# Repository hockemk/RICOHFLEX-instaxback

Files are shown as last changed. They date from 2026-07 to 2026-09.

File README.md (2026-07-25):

# RICOHFLEX instax back

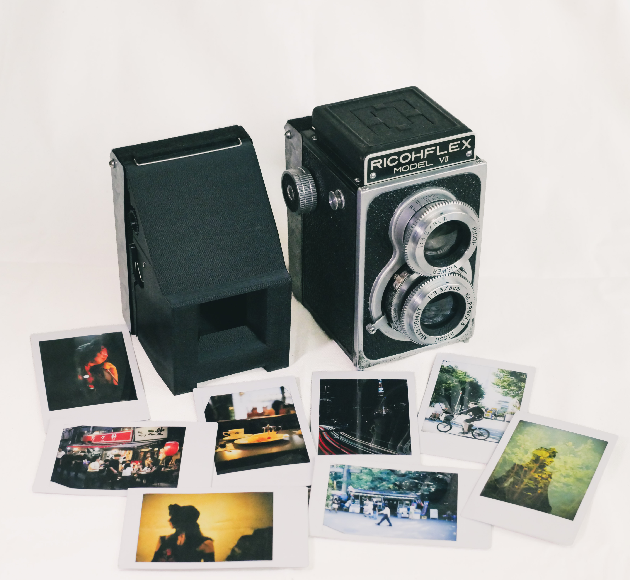
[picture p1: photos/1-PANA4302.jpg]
RICOHFLEX instax back


# RICOHFLEX instax back

RICOHFLEXで**instax mini**フィルムを使用できるようにするための改造キットです。

このリポジトリでは、キットを製作するために必要な3Dデータ、図面、部品表、マニュアルを公開しています。

本プロジェクトは3Dプリント部品を中心に構成されていますが、一部の重要部品には金属加工が必要です。そのため、ある程度の工作設備や加工経験を持つ方向けの内容となっています。

---

## 対応機種

ヘリコイド式のピント調整機構を持つRICOHFLEXに対応しています。

* RICOHFLEX III
* RICOHFLEX VI
* RICOHFLEX VII
など

RICOHFLEX Dia には対応していません。

---

## リポジトリ構成

### `data`

製作に必要なデータをまとめています。

* **bom** - 部品表
* **parts** - STL、STEP、部品図
* **assembly** – 組立に必要なSTEPファイルと組立に関する注意事項
* **extras** - レンズフードなどのおまけデータ

### `manual`

取扱説明書があります。

---

## はじめに

製作を始める前に、以下の手順で進めることをおすすめします。

1. 部品表（BOM）を確認する
2. STL・STEP・図面を確認し、必要な部品を製作する
3. 組立の注意事項とSTEPファイルを参照しながら組み立てる
4. 取扱説明書を確認して使用する

---

## フィードバック

不具合報告、改善案などはウェルカムです。

改良版や派生版を作ったらたら見せてね。

---

## ライセンス

個人での利用、改造、改良は大歓迎です。

本プロジェクトおよび本プロジェクトのデータを利用した製品の商用利用・販売は禁止とします。

詳しくは **LICENSE** をご確認ください。

---

## 開発について

このプロジェクトの開発経緯や設計に関する記事は、ブログで公開しています。同人誌にもまとめました。

開発記録や設計意図に興味のある方は、ぜひそちらもご覧ください。

---

## 連絡先

製作中に困ったことや不具合、対応機種の情報、改善案などがありましたら、お気軽にご連絡ください。

すべてのお問い合わせに対応できるとは限りませんが、お答えできる範囲でできるだけお手伝いします。

また、完成したカメラや撮影した写真、改良版や派生作品なども、ぜひ見せていただけると嬉しいです。

- Blog: https://hocke.hatenablog.com/archive/category/RICOHFLEX%20instax%20back
- X (Twitter): https://x.com/hocke_mk
- Instagram: https://www.instagram.com/hocke__/

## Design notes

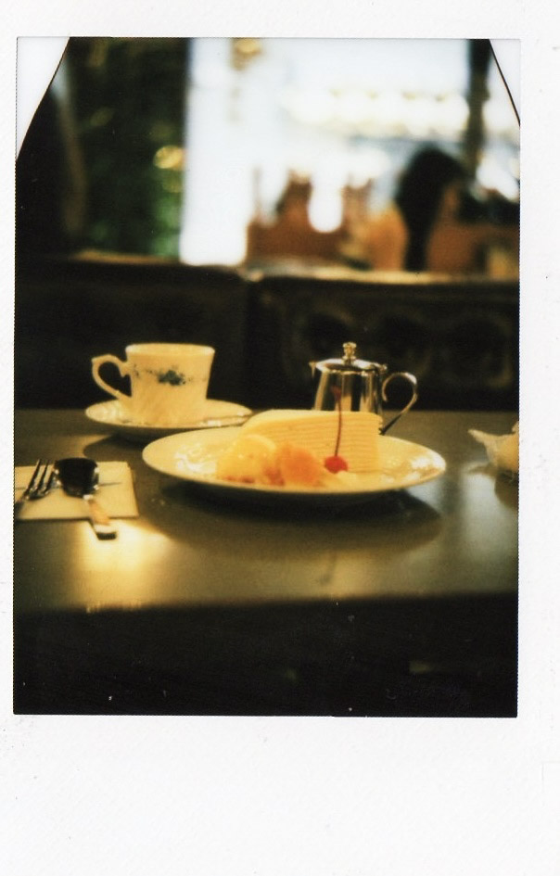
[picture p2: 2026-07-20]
photos/4-IMG_5428.jpg

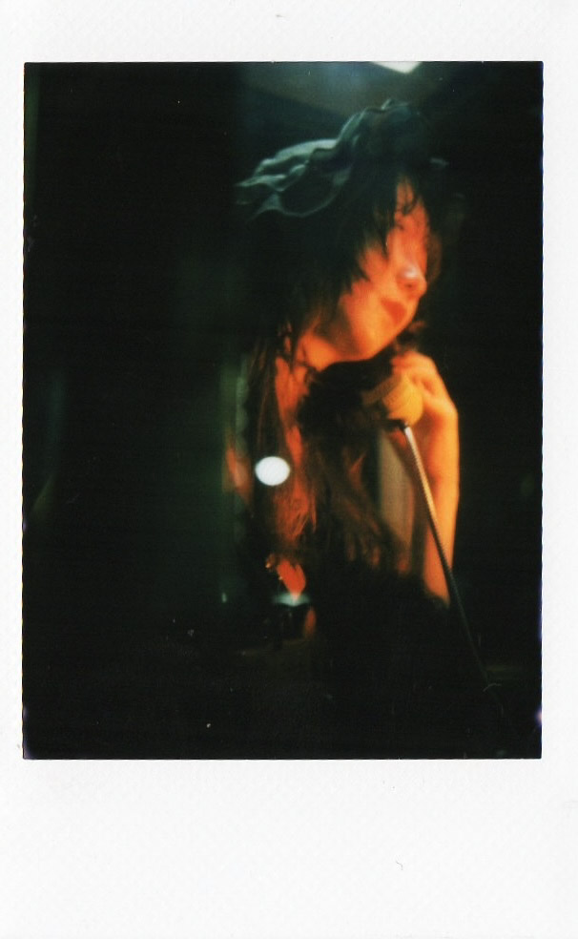
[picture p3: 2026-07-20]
photos/10-IMG_5407.jpg

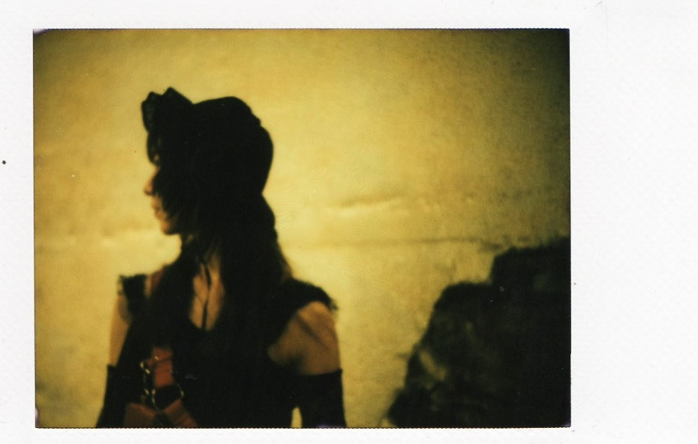
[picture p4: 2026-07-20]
photos/8-IMG_5409.jpg

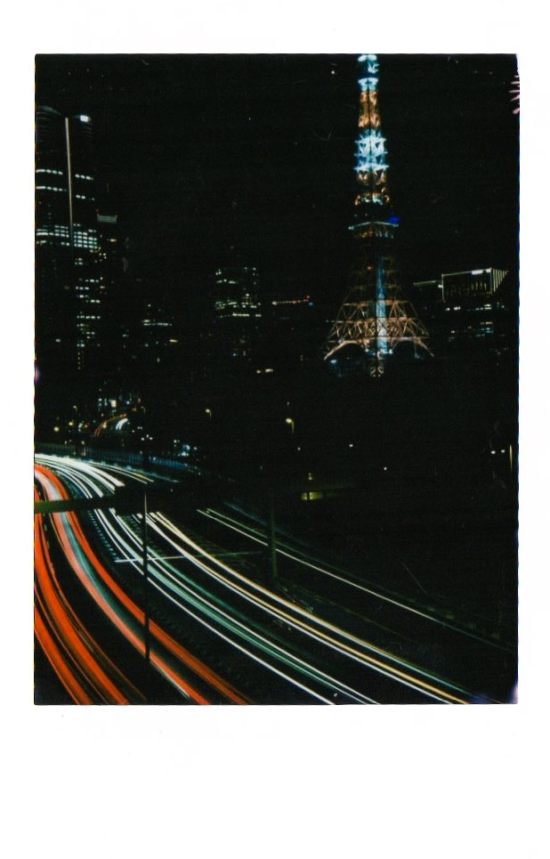
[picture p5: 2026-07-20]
photos/1-IMG_5432.jpg

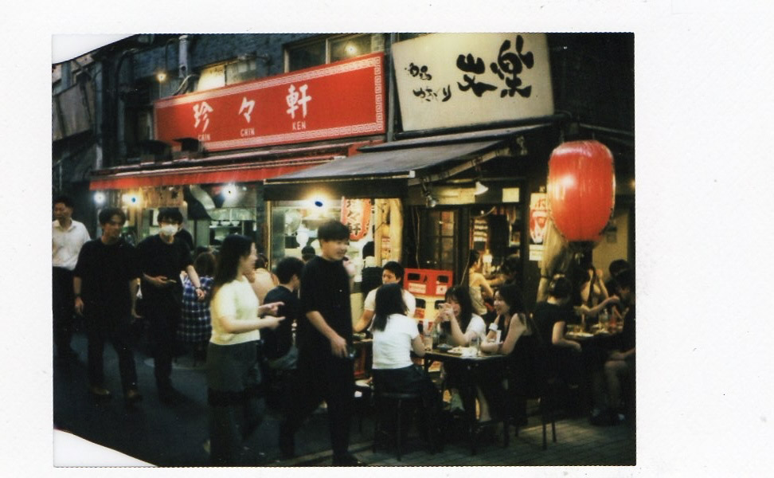
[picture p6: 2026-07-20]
photos/2-IMG_5430.jpg

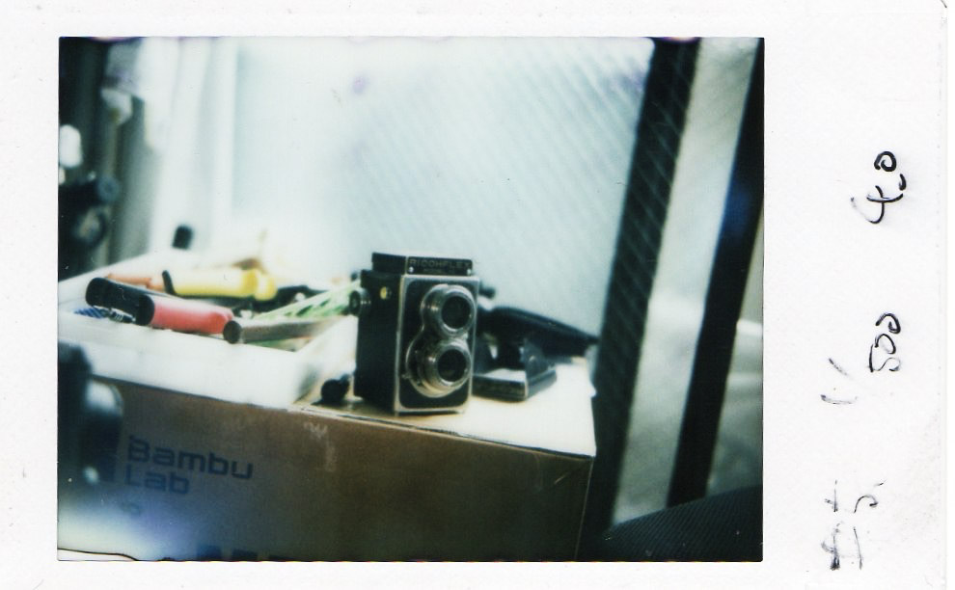
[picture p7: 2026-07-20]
photos/7-IMG_5414.jpg

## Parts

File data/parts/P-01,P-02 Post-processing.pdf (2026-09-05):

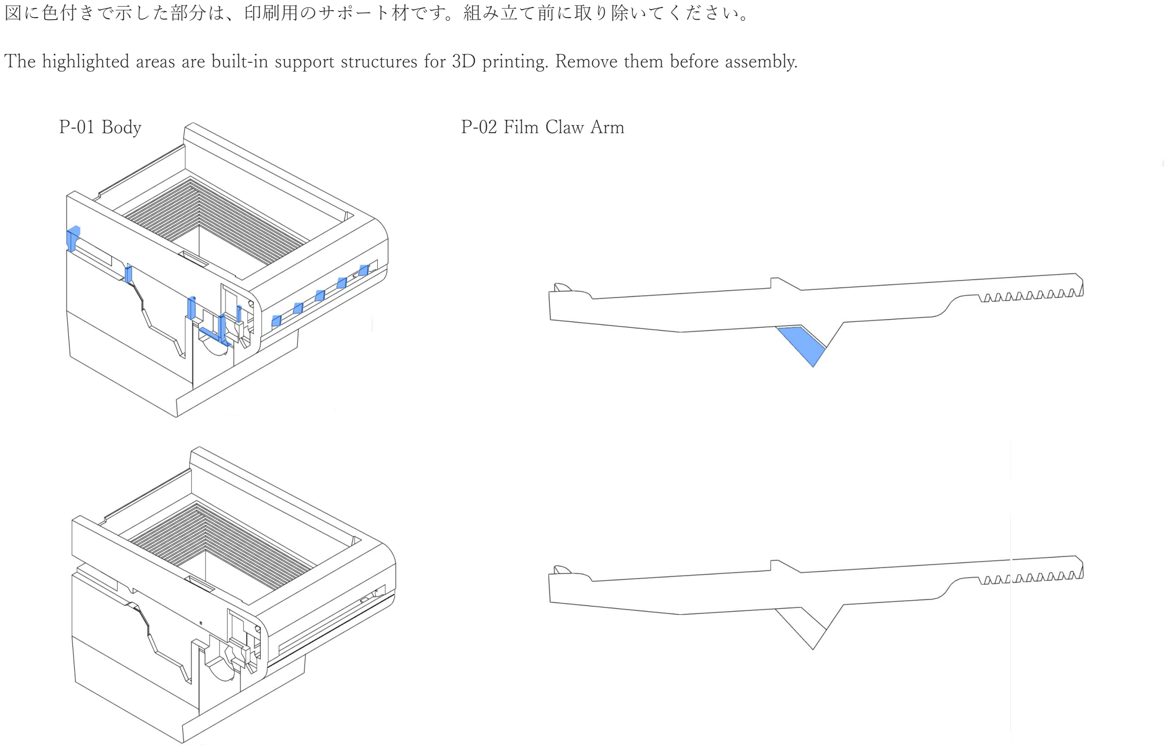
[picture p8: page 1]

図に色付きで示した部分は、印刷用のサポート材です。組み立て前に取り除いてください。

The highlighted areas are built-in support structures for 3D printing. Remove them before assembly.

P-01 Body | P-02 Film Claw Arm

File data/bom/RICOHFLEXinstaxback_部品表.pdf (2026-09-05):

BOM
Part No. | Part name | Qty. | Material/Stock | Specification | Files | Notes
P-01 | Body | 1 | Printed | 0.4mm nozzle | STEP/STL/PDF | Remove the built-in support structures and clean up as needed.
C-01 | Light Seal Felt Strip | 1 | Felt | 5 mm wide × 254 mm | | Adhesive-backed felt recommended. Approx.1mm thick.
C-02 | Light Seal Felt Sheet | 1 | Felt | | SVG/PDF | Cut to match template. Adhesive-backed felt recommended. Approx.1mm thick.
M-01 | Retaining Clip | 1 | Steel Round Bar | Ø1 | PDF | Bend as shown
M-02 | Film Claw | 1 | Stainless Steel Spring Wire | Ø0.4 | PDF | Bend as shown
P-02 | Film Claw Arm | 1 | Printed | 0.2mm nozzle | STEP/STL/PDF | Remove the built-in support structures and clean up as needed.
M-03 | Film Claw Arm Spring | 1 | Stainless Steel Spring Wire | Ø0.4 | SVG | Bend as shown
P-03 | Lever | 1 | Printed | 0.4mm nozzle | STEP/STL
M-04 | Lever Pivot Pin | 1 | Steel Round Bar | Ø0.8 × 4 mm | | Cut to length
P-04 | Knob Gear | 1 | Printed | 0.2mm nozzle | STEP/STL
P-05 | Idler Gear | 1 | Printed | 0.2mm nozzle | STEP/STL
P-06 | Front Roller Gear | 1 | Printed | 0.2mm nozzle | STEP/STL
P-07 | Rear Roller Gear | 1 | Printed | 0.2mm nozzle | STEP/STL
M-05 | Roller Gear Pin | 2 | Steel Round Bar | Ø0.8 × 4.4 mm | | Cut to length
M-06 | Roller Shaft | 2 | Steel Round Bar | Ø3 | PDF | Cut to length and drill holes
M-07 | Roller | 2 | Aluminium Pipe | OD 7 mm × ID 3 mm | PDF | Cut to length and drill a hole
M-08 | Roller Shaft Pin | 2 | Steel Round Bar | Ø0.8 × 5 ｍｍ | | Cut to length
P-08 | Left Roller Retainer | 1 | Printed | 0.4mm nozzle | STEP/STL
P-09 | Right Roller Retainer | 1 | Printed | 0.4mm nozzle | STEP/STL
P-10 | Shaft Spacer | 1 | Printed | 0.4mm nozzle | STEP/STL
M-09 | Roller Pressure Spring | 2 | Stainless Steel Spring Wire | Ø0.8 | SVG | A binder clip spring is a good substitute.
P-11 | Roller Pressure Spring Seat | 1 | Printed | 0.4mm nozzle | STEP/STL
P-12 | Roller Shaft Collar | 2 | Printed | 0.4mm nozzle | STEP/STL
M-10 | Bearing Plate | 2 | Brass Plate | t0.5 | PDF | This part can be made with a drill and files, but a milling machine makes the job much easier.
M-11 | Back Panel | 1 | Metal Sheet | t0.3 | STEP/DXF | Cut and bend as shown. Any sheet metal from approximately 0.2 mm to 0.8 mm thick should work.
C-03 | Film Pack Spring | 2 | Steel | Ø9 × 15 mm Ø0.5 | | Maximum recommended size: Ø9 mm×16 mm, wire Ø0.6 mm. A free length of 14-16 mm works well.
M-12 | Latch Stud | 1 | Steel Round Bar | Ø2 × 2 mm | | Cut to length and weld
C-04 | Foam Tape | 1 | Foam Tape | 3 mm thick
C-05 | Slotted Screw | 2 | Metal | M3 × 12 mm | | Any M3 screw will work. Slotted screws are used only for appearance.
C-06 | Back Panel Leather | 1 | Leather | | SVG/PDF | Cut to match template

3Dプリント部品は、±0.1 mm 以内の寸法精度で印刷してください。推奨積層ピッチは、0.4mmノズルでは0.16mm、0.2mmノズルでは0.1mmです。 フィラメントは、十分な寸法精度と強度が得られるものであればなんでもいいです。私は PLA+ を使用しましたが、PLA-CF、ABS、ナイロンなど、同等以上の性能を持つ材料であれば問題なく使用できるはずです。 この設計は厳密な仕様書ではありません。ご自身の設備や加工方法に合わせて、製作しやすい材料や工法を自由に選択してください。入手しやすく、また扱いやすい材料を使用しちゃってください。 摺動部品については、耐摩耗性を考慮した材料を選択することをおすすめします。 この設計を忠実に再現することよりも、確実に動作することを優先してください。動作性や製作性が向上するのであれば、寸法や材料を変更して問題ありません。 改造改良大歓迎。作ったり改造したらぜひ見せてね。

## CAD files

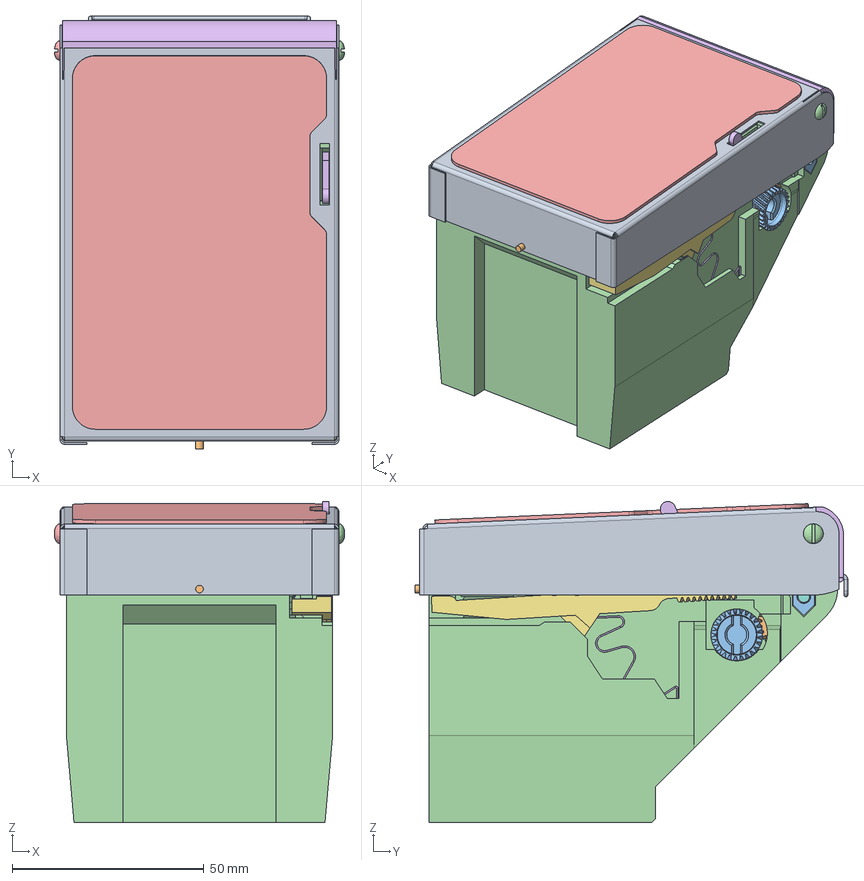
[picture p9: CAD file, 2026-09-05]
data/assemble/Complete_Assembly.step
75.8 x 113.0 x 83.8 mm

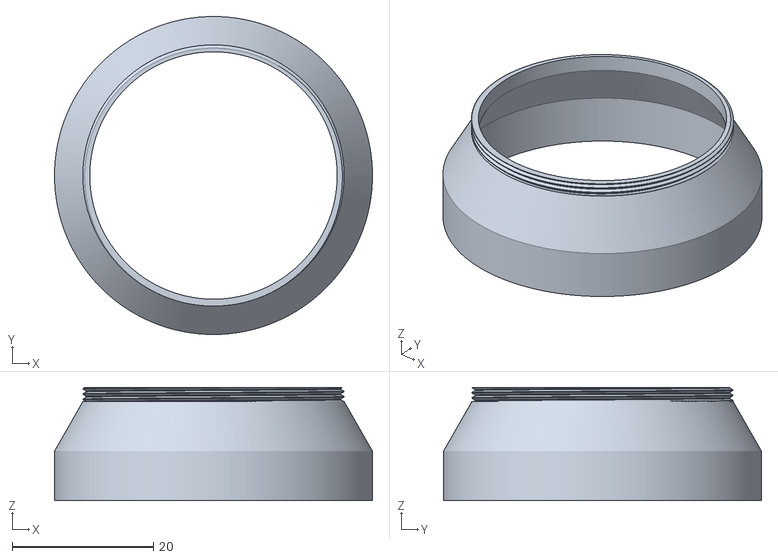
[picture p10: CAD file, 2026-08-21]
data/extras/LensHood37mm.stl
45.0 x 45.0 x 16.0

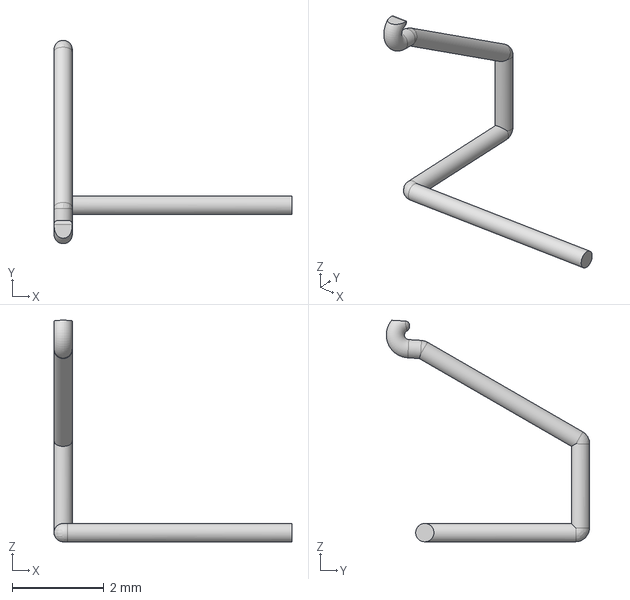
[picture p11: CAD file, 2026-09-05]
data/parts/M-02_FilmClaw.step
5.20 x 4.44 x 4.84 mm

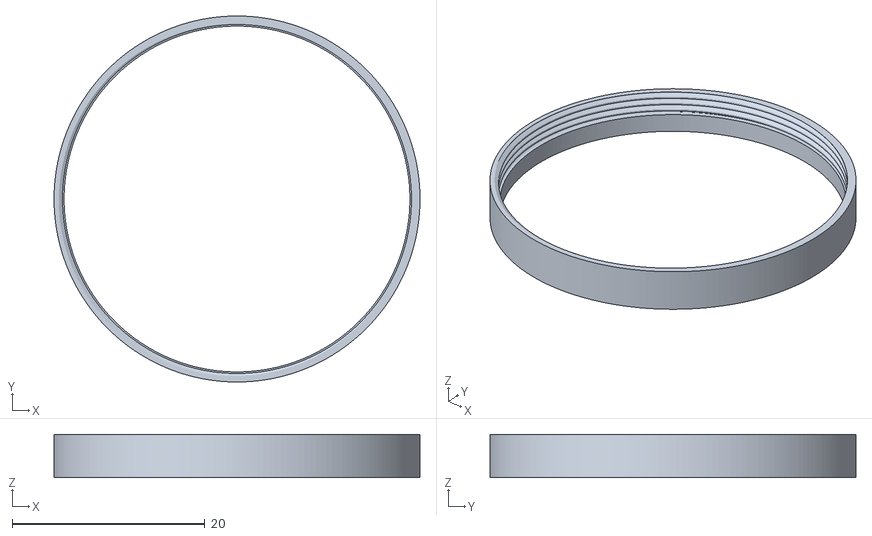
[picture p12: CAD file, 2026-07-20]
data/extras/FilterAdapter37mm.stl
38.0 x 38.0 x 4.50

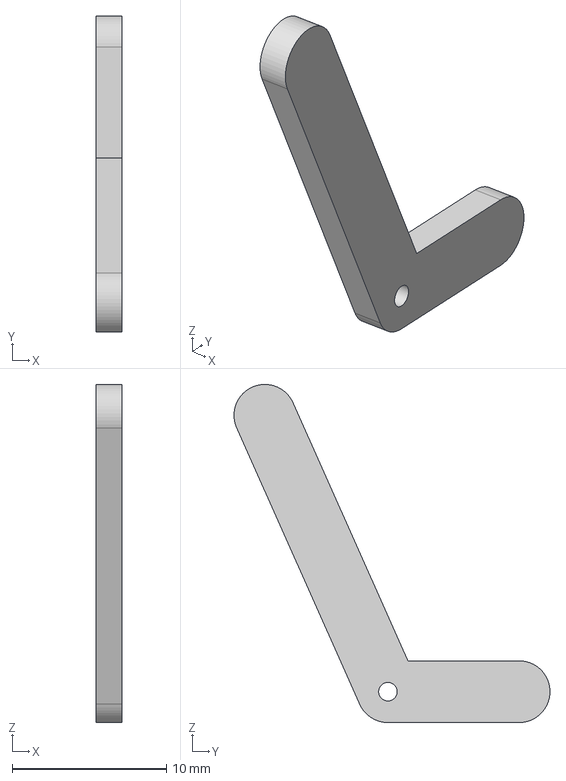
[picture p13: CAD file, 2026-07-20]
data/parts/P-03_Lever.step
1.70 x 20.5 x 21.9 mm

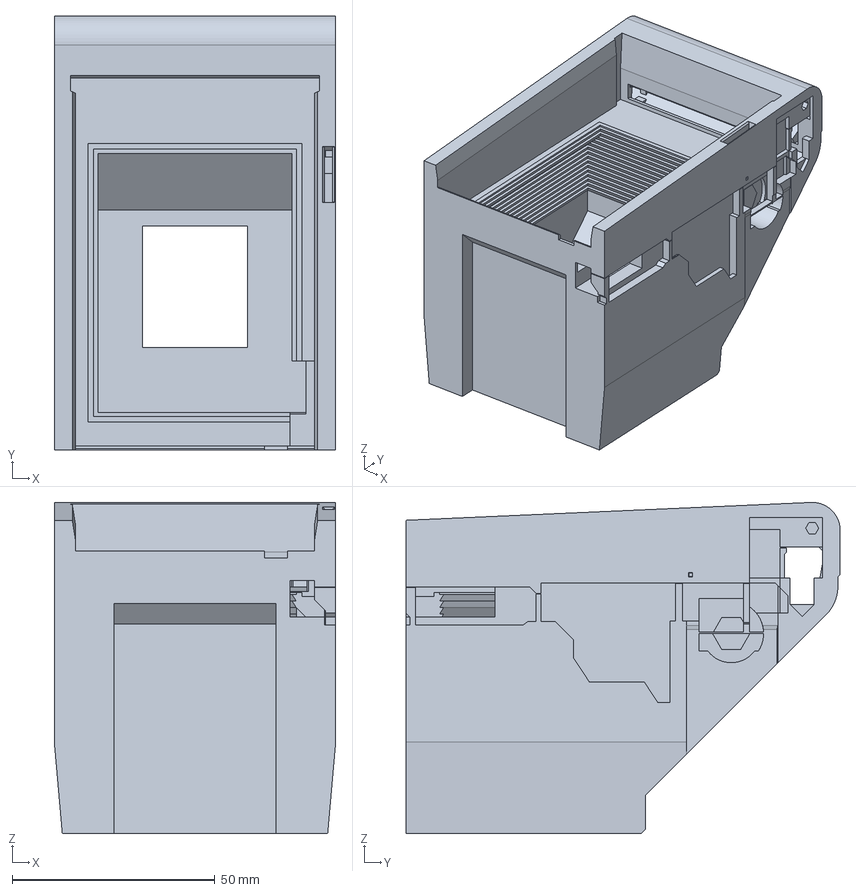
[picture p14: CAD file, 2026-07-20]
data/parts/P-01_body.step
69.5 x 107.2 x 81.8 mm

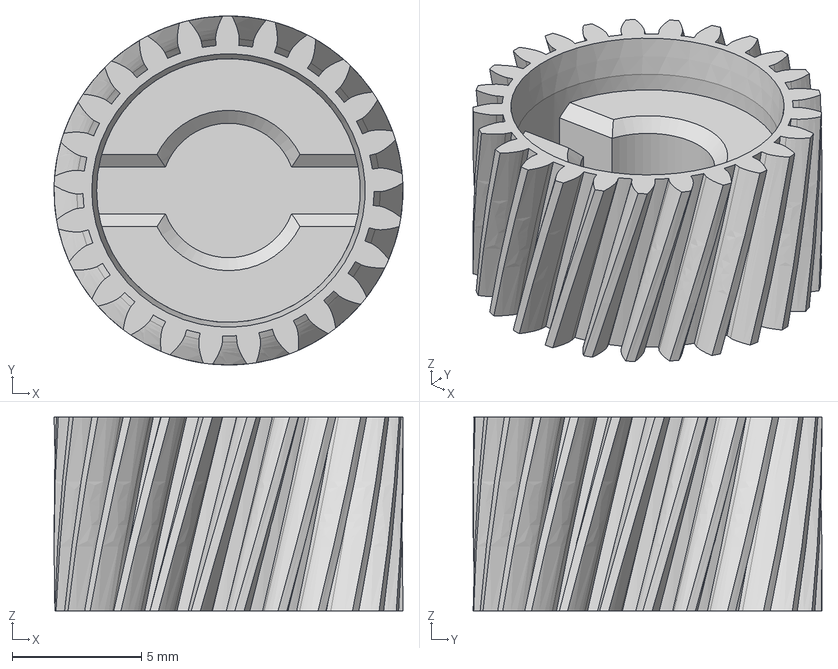
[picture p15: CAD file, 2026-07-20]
data/parts/P-04_KnobGear.step
13.5 x 13.5 x 7.50 mm

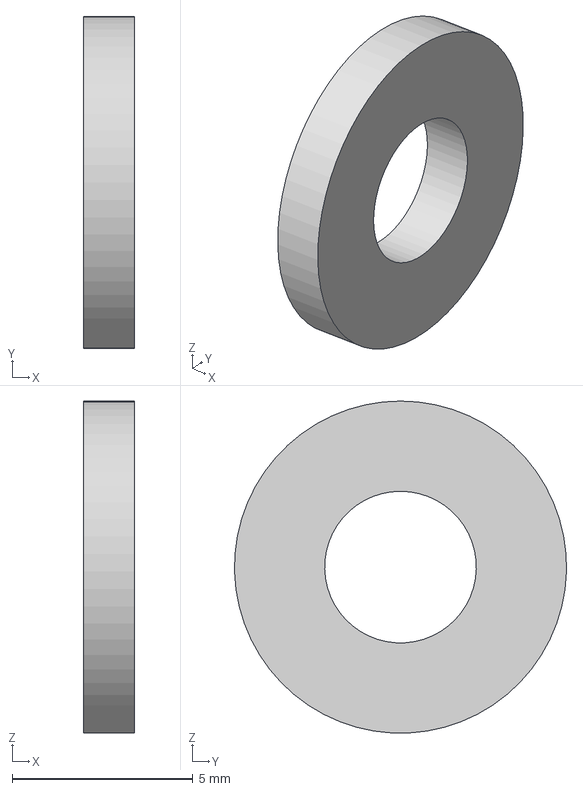
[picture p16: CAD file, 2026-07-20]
data/parts/P-10_ShaftSpacer.step
1.40 x 9.20 x 9.19 mm

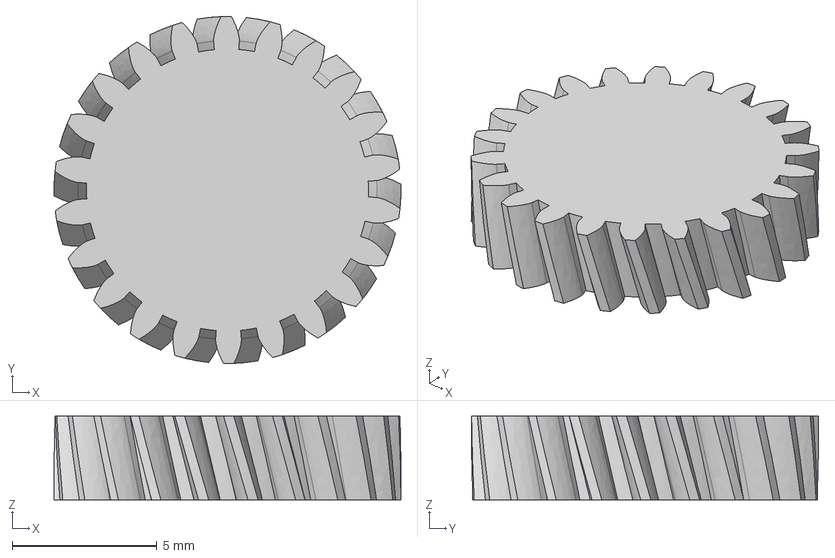
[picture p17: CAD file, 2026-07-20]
data/parts/P-05_IdlerGear.step
12.0 x 12.0 x 2.90 mm

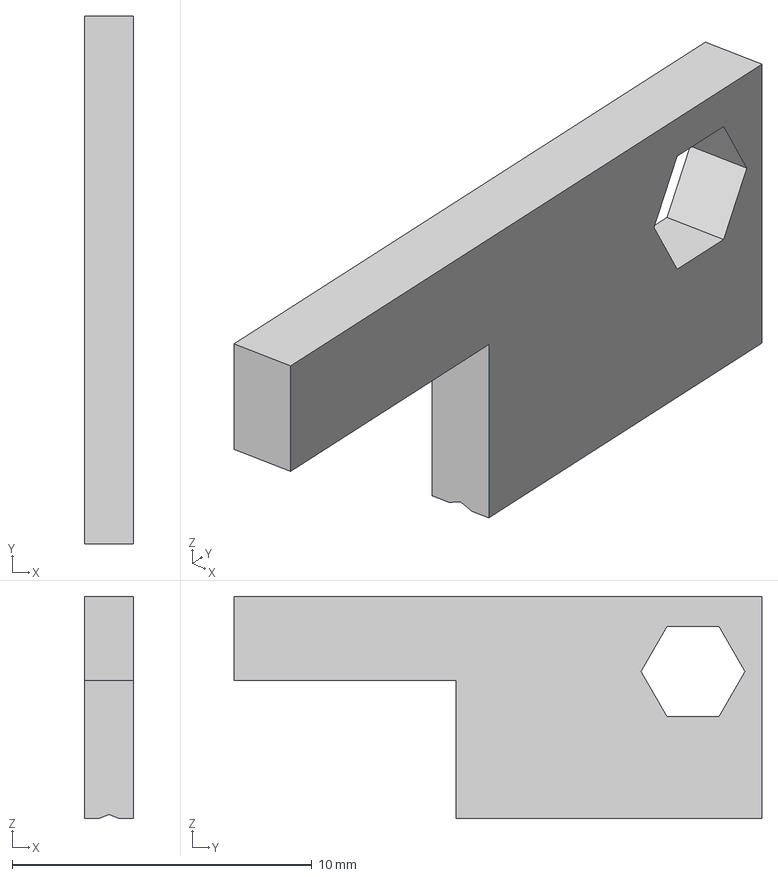
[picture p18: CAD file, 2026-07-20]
data/parts/P-11_RollerPressureSpringSeat.step
1.65 x 17.6 x 7.40 mm

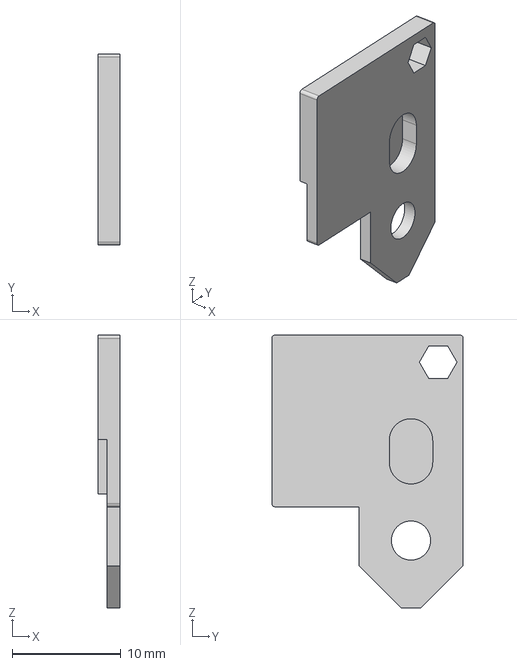
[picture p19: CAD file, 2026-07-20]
data/parts/P-08_LeftRollerRetainer.step
2.00 x 17.6 x 25.1 mm

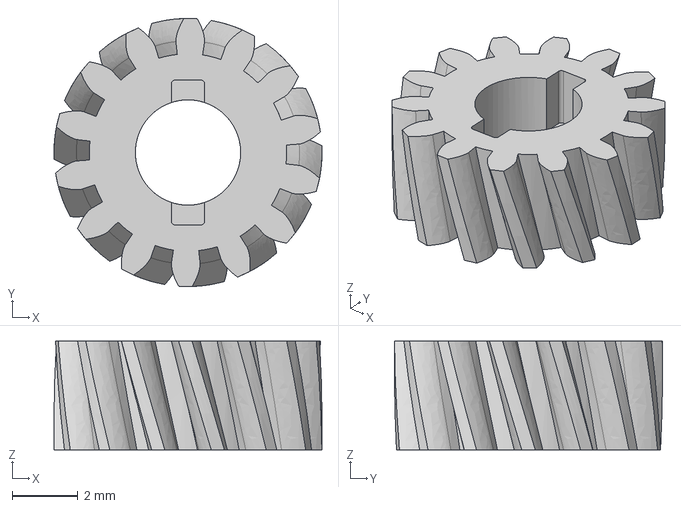
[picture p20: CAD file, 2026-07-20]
data/parts/P-07_RearRollerGear.step
8.14 x 8.15 x 3.30 mm

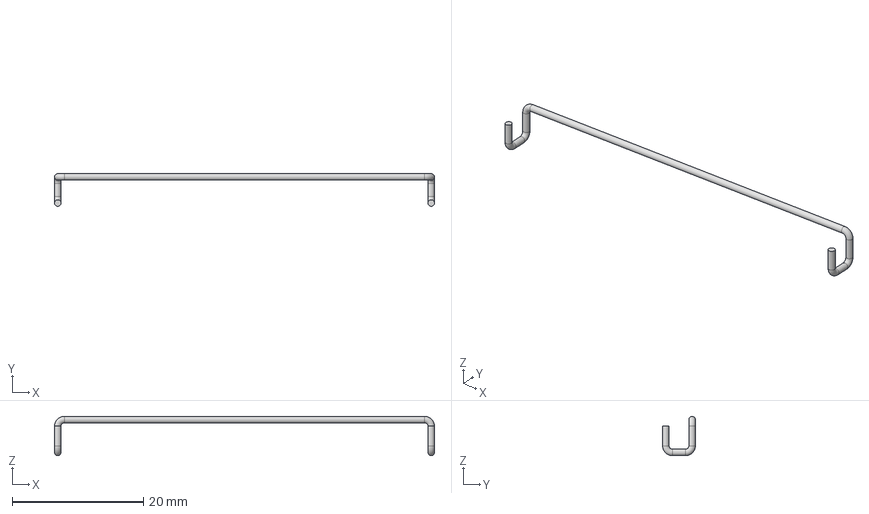
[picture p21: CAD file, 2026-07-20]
data/parts/M-01_RetainingClip.step
58.0 x 5.00 x 6.00 mm

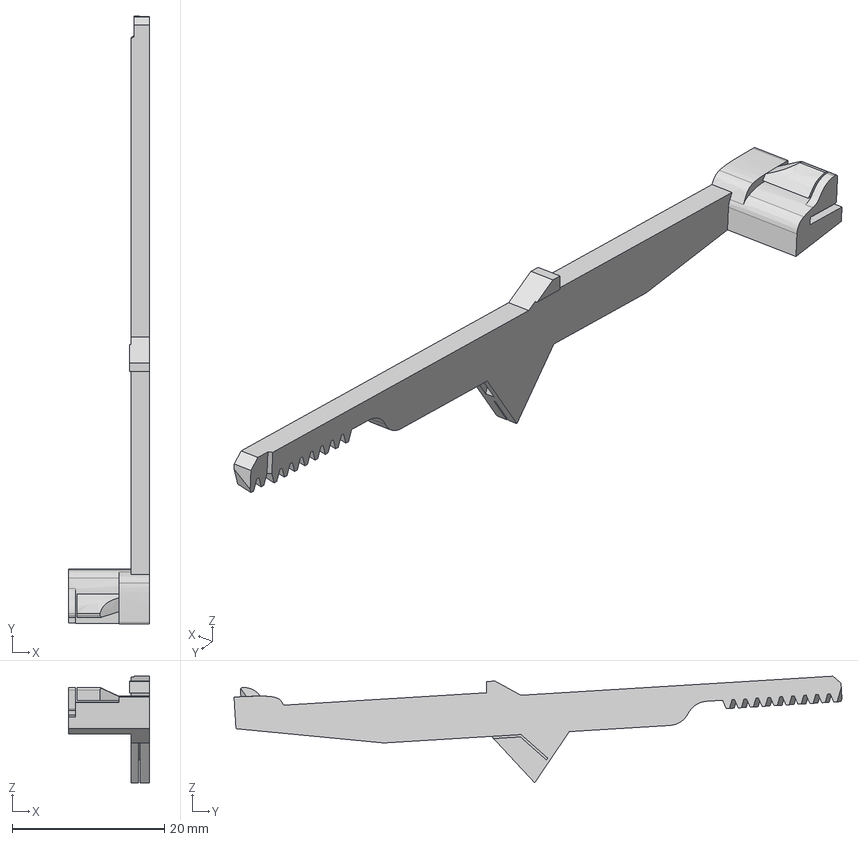
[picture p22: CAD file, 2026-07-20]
data/parts/P-02_FilmClawArm.step
10.6 x 79.7 x 14.0 mm

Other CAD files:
data/parts/P-09_RightRollerRetainer.step
data/parts/P-12_RollerShaftCollar.step
data/parts/P-06_FrontRollerGear.step
data/parts/M-11_BackPanel.step
data/parts/M-11_BackPanel.dxf
data/parts/P-01_body.stl
data/parts/P-02_FilmClawArm.stl
data/parts/P-03_Lever.stl
data/parts/P-04_KnobGear.stl
data/parts/P-05_IdlerGear.stl
data/parts/P-06_FrontRollerGear.stl
data/parts/P-07_RearRollerGear.stl
data/parts/P-08_LeftRollerRetainer.stl
data/parts/P-09_RightRollerRetainer.stl
data/parts/P-10_ShaftSpacer.stl
data/parts/P-11_RollerPressureSpringSeat.stl
data/parts/P-12_RollerShaftCollar.stl

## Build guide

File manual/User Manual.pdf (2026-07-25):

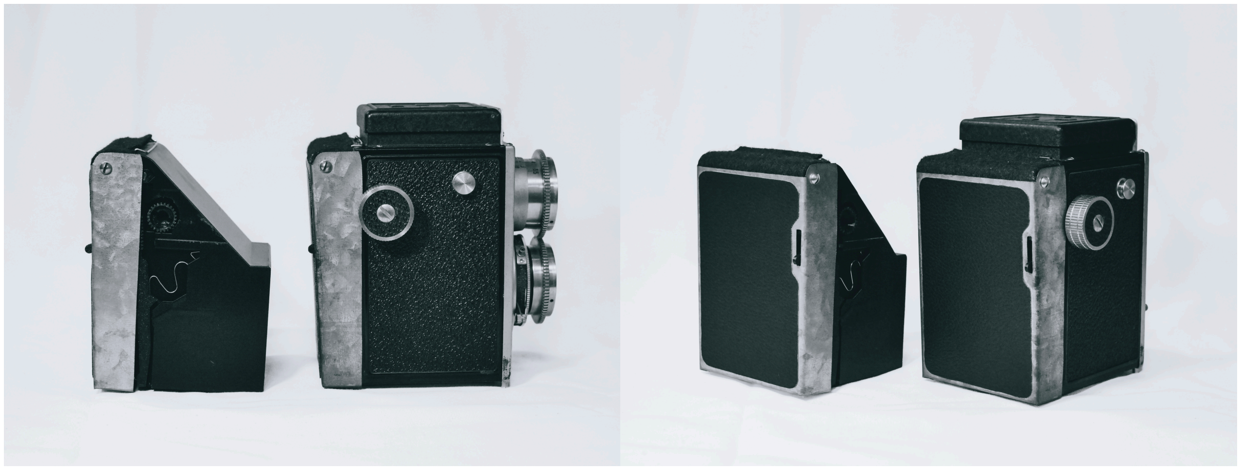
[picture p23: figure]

## Install the Kit

# 〜How to use〜

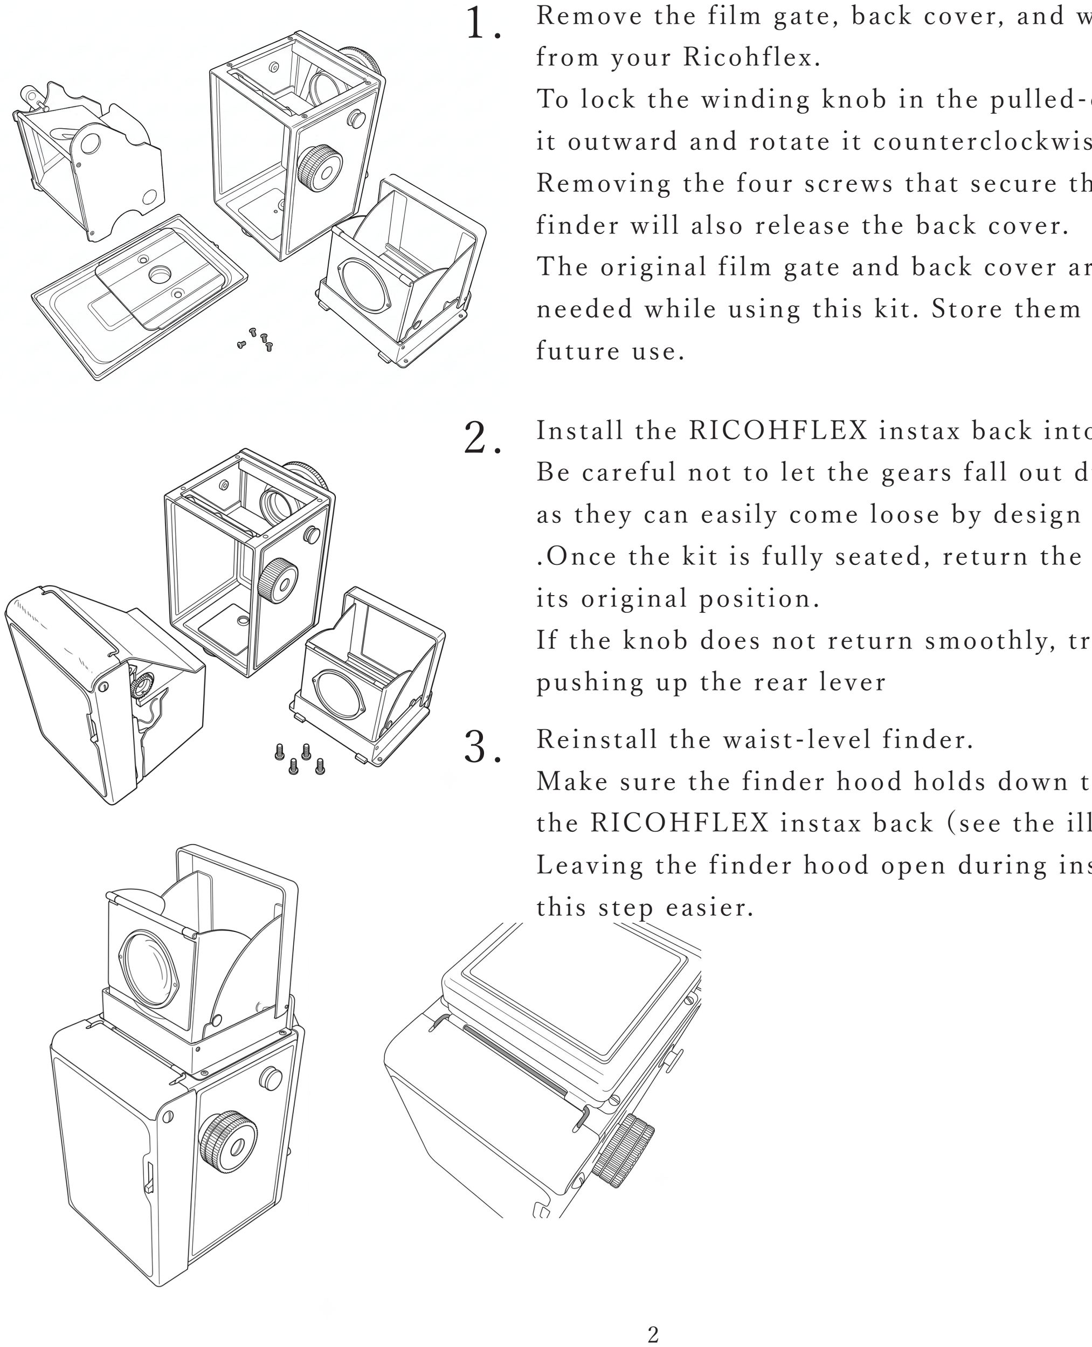
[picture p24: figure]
from your Ricohflex.; future use.; as they can easily come loose by design; its original position.; pushing up the rear lever; Reinstall the waist-level finder.; this step easier.

Remove the film gate, back cover, and waist-level finder

To lock the winding knob in the pulled-out position, pull it outward and rotate it counterclockwise.
Removing the four screws that secure the waist-level finder will also release the back cover.
The original film gate and back cover are no longer needed while using this kit. Store them in a safe place for

Install the RICOHFLEX instax back into the camera.
Be careful not to let the gears fall out during installation,

.Once the kit is fully seated, return the winding knob to

If the knob does not return smoothly, try rotating it while

Make sure the finder hood holds down the upper clip of the RICOHFLEX instax back (see the illustration below). Leaving the finder hood open during installation makes

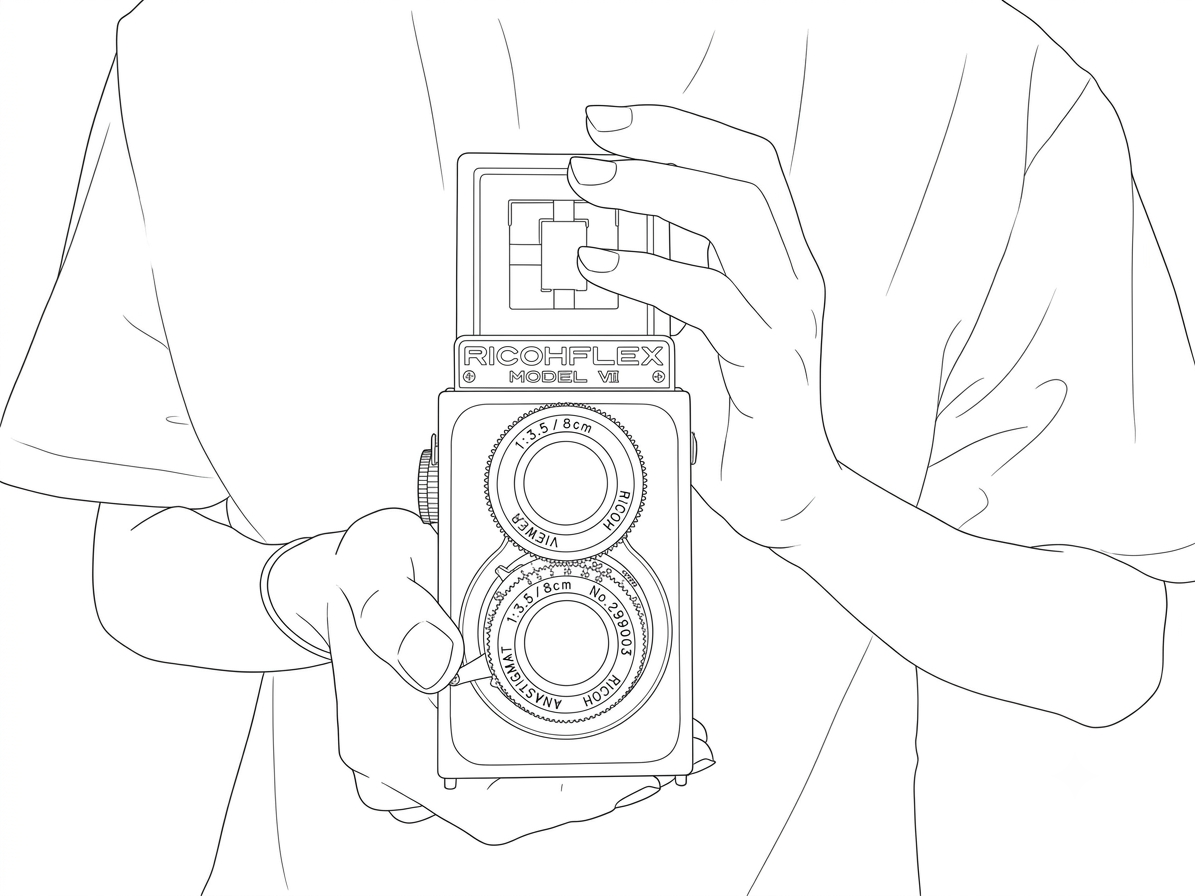
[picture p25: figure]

3

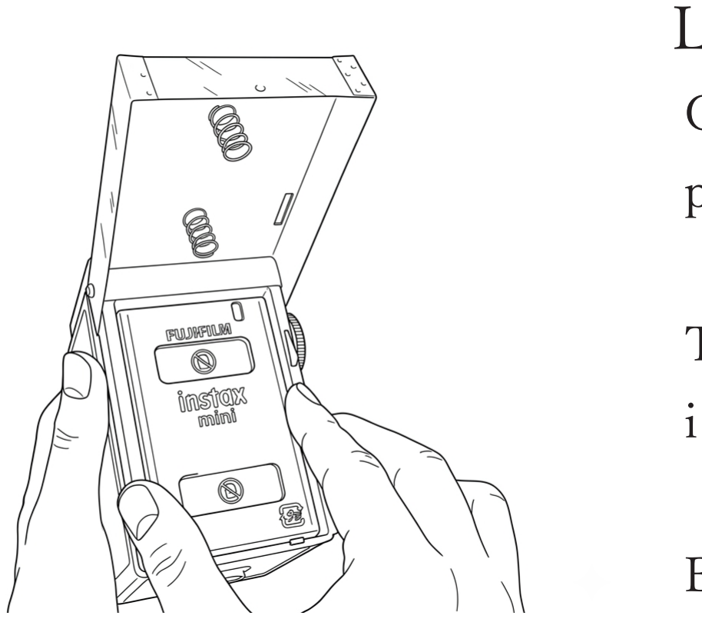
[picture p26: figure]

## Load the Film

Open the back cover and insert an instax mini film pack.

The film is correctly oriented when the yellow mark is visible in the upper-right corner.

Be careful not to catch the film pack on the spring.
SHOOT.

## Eject the Film

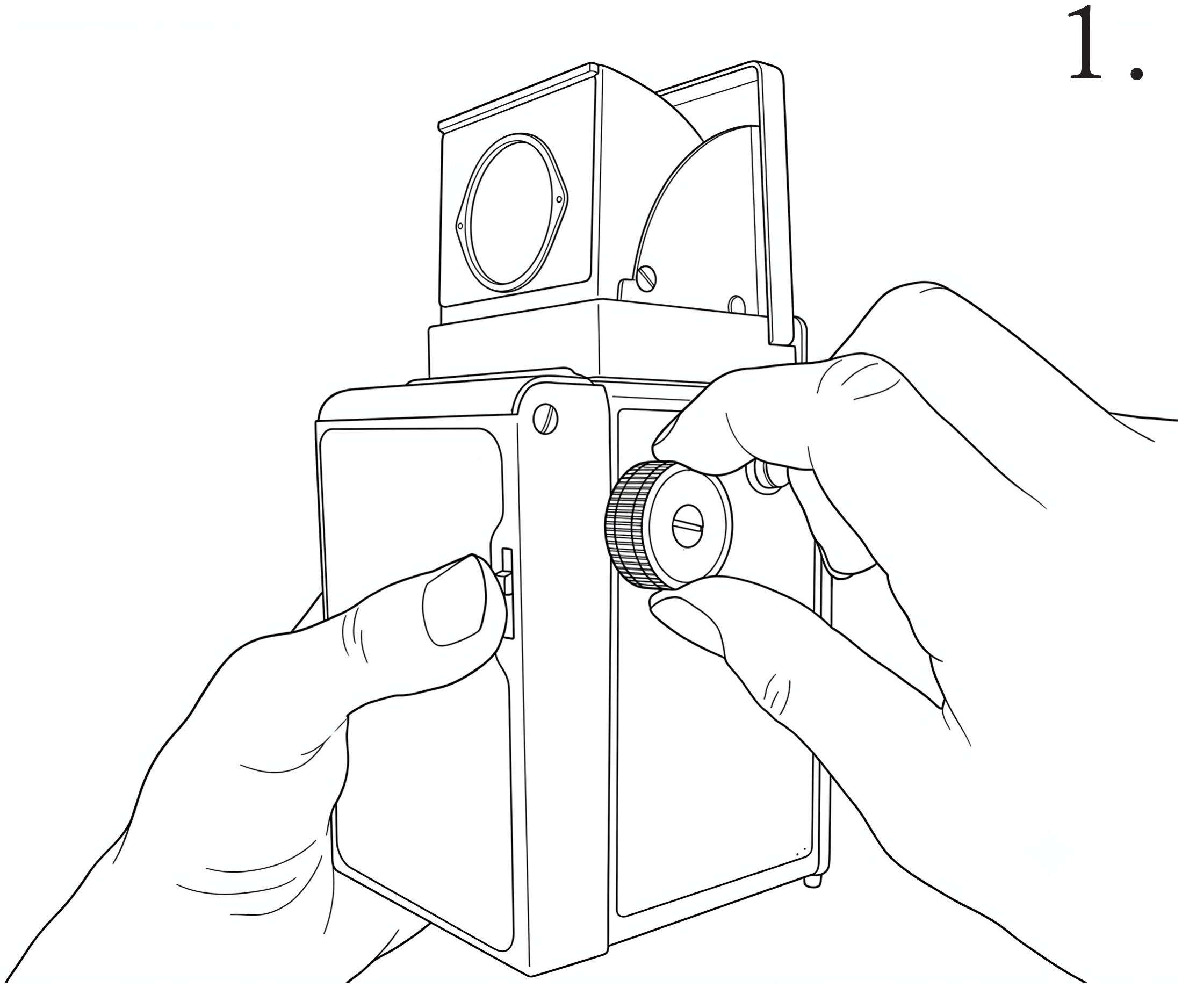
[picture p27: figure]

Push the rear lever all the way upward.
Do not release the lever during this operation.
While holding the lever up, rotate the winding knob.
If the film is advancing correctly, the knob will suddenly become noticeably heavier.
Continue turning until the knob comes to a complete stop. This is typically about one-third of a turn.
If you are unsure whether you felt the increase in resistance, simply continue turning until the knob stops before proceeding.

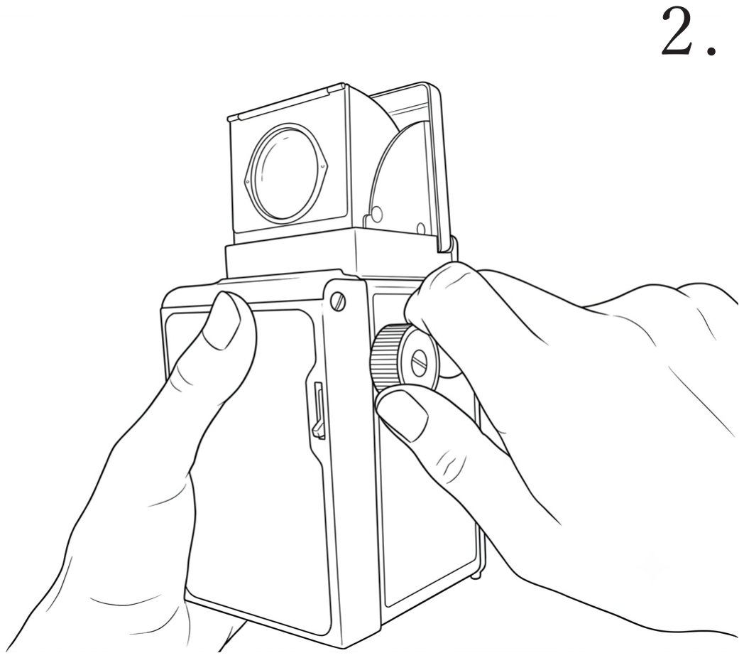
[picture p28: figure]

Release the lever and continue turning the winding knob until the print is fully ejected.
If the print does not eject, repeat the procedure from Step 1.
Never operate the rear lever while turning the winding knob, as this may cause the film to jam or damage the mechanism.
The print will develop in approximately 90 seconds.

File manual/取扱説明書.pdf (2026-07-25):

# RICOHFLEX instax back

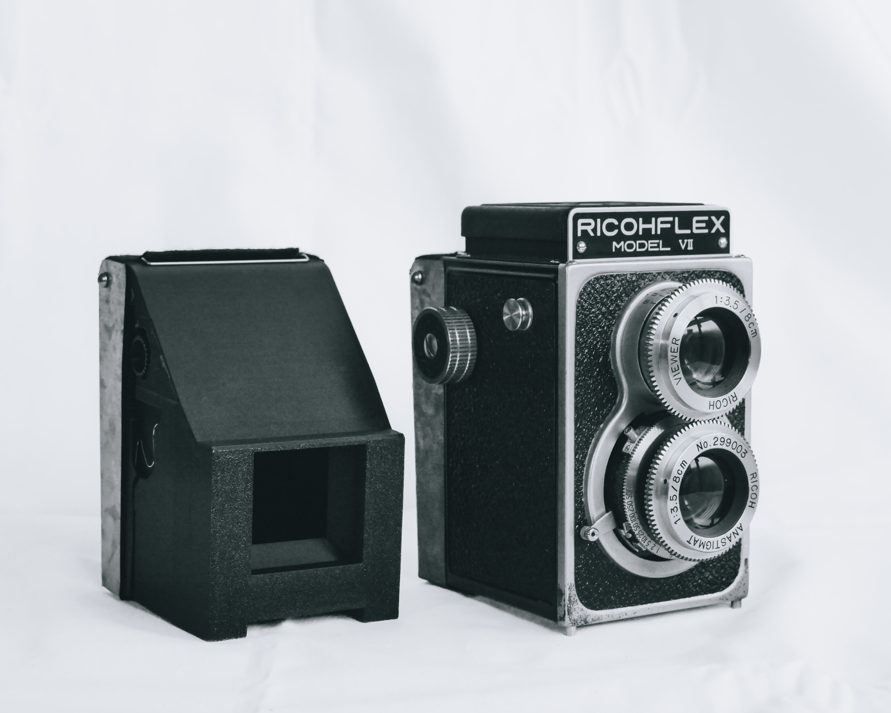
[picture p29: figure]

対応機種 | リコーフレックスⅢ/Ⅵ/Ⅶなど（ヘリコイド式モデル）
使用フィルム | instax mini （チェキフィルム）
撮影画面サイズ | 62×46 mm
レンズ | RICOH ANASTIGMAT 80mm 1:3.5
フォーカス | マニュアルフォーカス
シャッター | B-1/500 （カメラ本体による）
フィルム送り | 手動
電源 | 不要
多重露光 | 対応

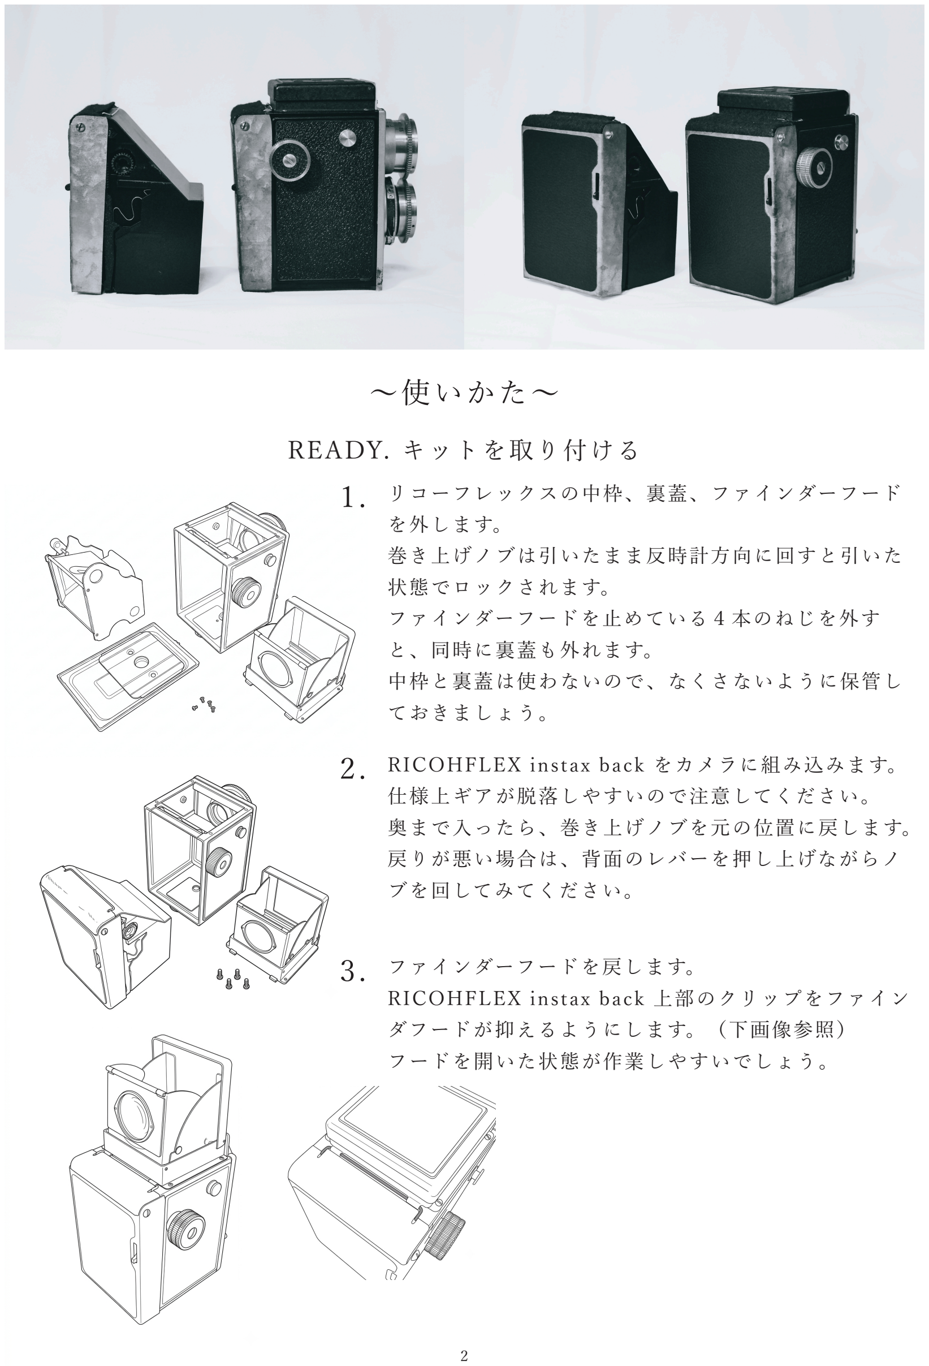
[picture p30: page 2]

### READY. キットを取り付ける

## 〜使いかた〜

リコーフレックスの中枠、裏蓋、ファインダーフード
を外します。
巻き上げノブは引いたまま反時計方向に回すと引いた
状態でロックされます。
ファインダーフードを止めている４本のねじを外す
と、同時に裏蓋も外れます。
中枠と裏蓋は使わないので、なくさないように保管し
ておきましょう。

RICOHFLEX instax back をカメラに組み込みます。 仕様上ギアが脱落しやすいので注意してください。
奥まで入ったら、巻き上げノブを元の位置に戻します。
戻りが悪い場合は、背面のレバーを押し上げながらノ
ブを回してみてください。

ファインダーフードを戻します。
RICOHFLEX instax back 上部のクリップをファイン ダフードが抑えるようにします。（下画像参照）
フードを開いた状態が作業しやすいでしょう。

3.

1.

2.

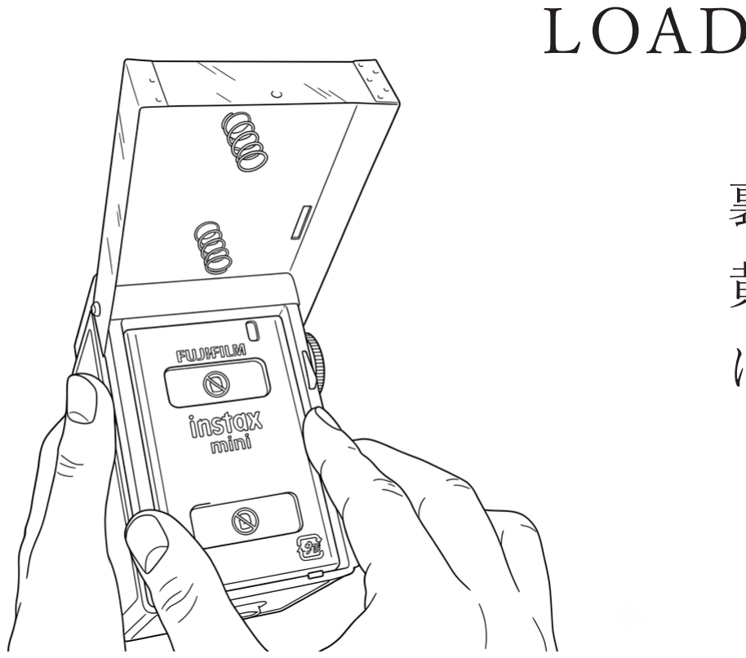
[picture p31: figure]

### LOAD. フィルムを入れる

裏蓋を開けてフィルムをセットします。
黄色いマークが右上に見えるのが正しい向きです。
ばねにフィルムを引っ掛けないよう注意してください。

### SHOOT. 撮る


### EJECT. チェキを取り出す

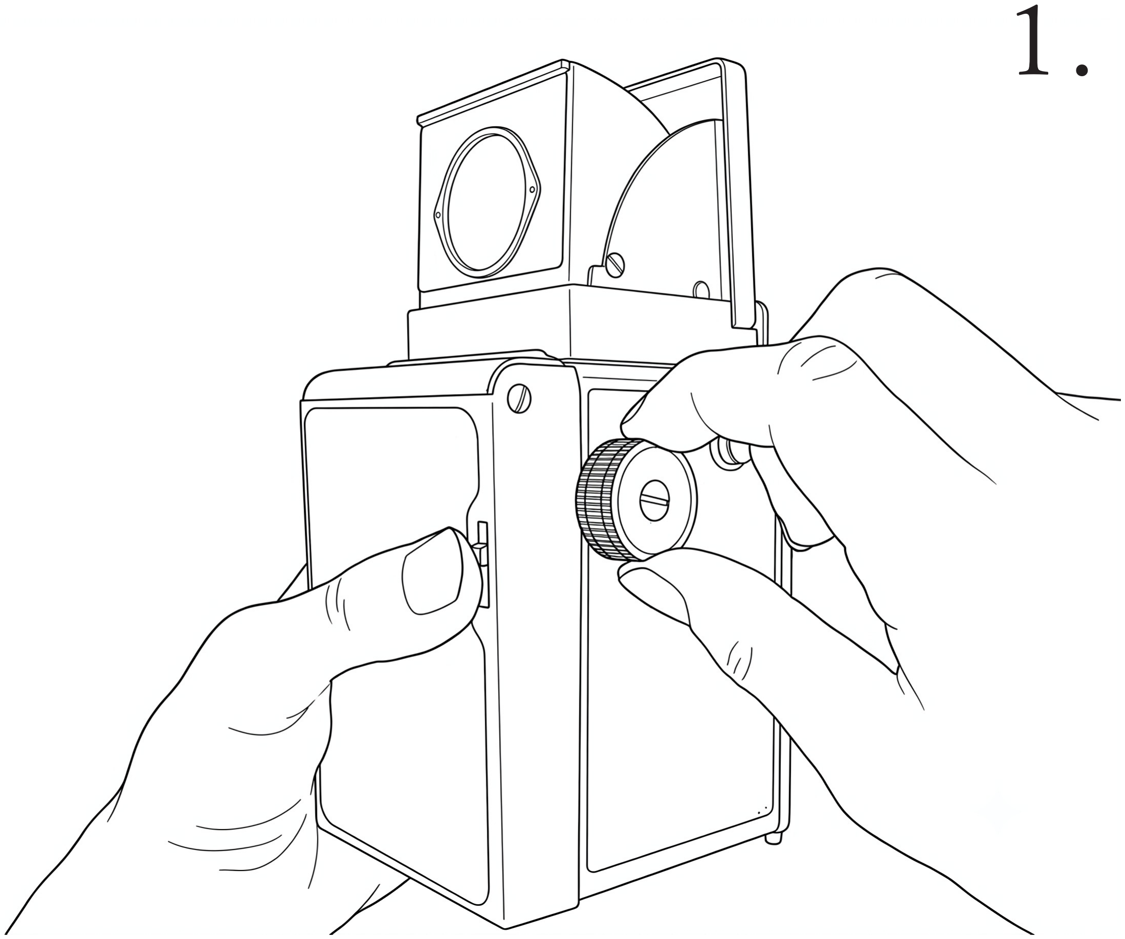
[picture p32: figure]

背面のレバーを一番上まで押し上げます。この操作の間
はレバーから手を離さないでください。
レバーを押し上げたままノブを回します。
正常にフィルムが送られていれば、途中でぐっとノブが
重たくなります。そこからさらにノブが回らなくなるま
で、しっかりと回します。目安は1/3回転です。

ノブが重たくなったか不明な場合でも、ノブの回転が止
まるまで回して次の手順に進んでください。

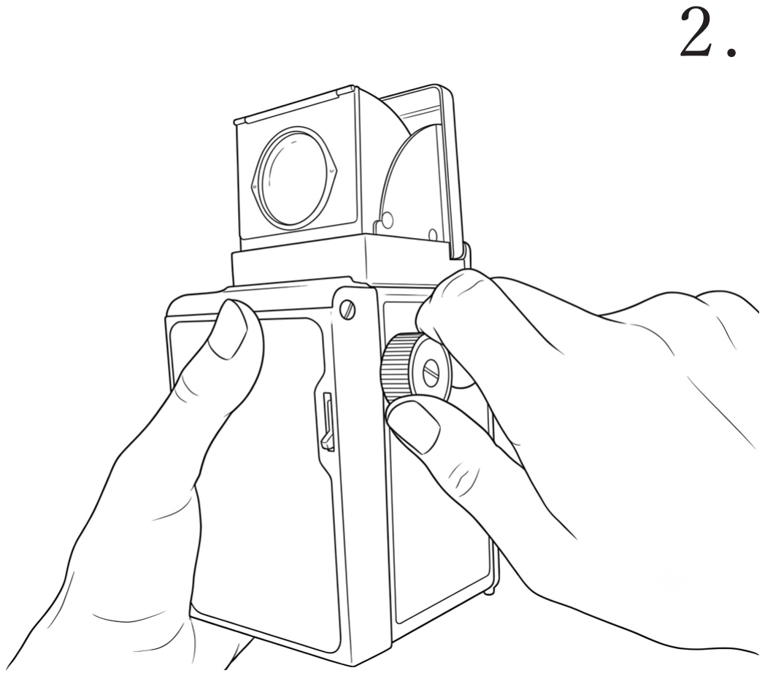
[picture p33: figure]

レバーから手を離し、チェキが完全に出てくるまでノブ
を回します。
チェキが出てこない場合は、先の手順を初めから繰り返
してください。

ノブを操作している最中には、絶対にレバーに触れない
でください、チェキの詰まりや故障の原因となります。

出てきたチェキは90秒ほどで現像します。

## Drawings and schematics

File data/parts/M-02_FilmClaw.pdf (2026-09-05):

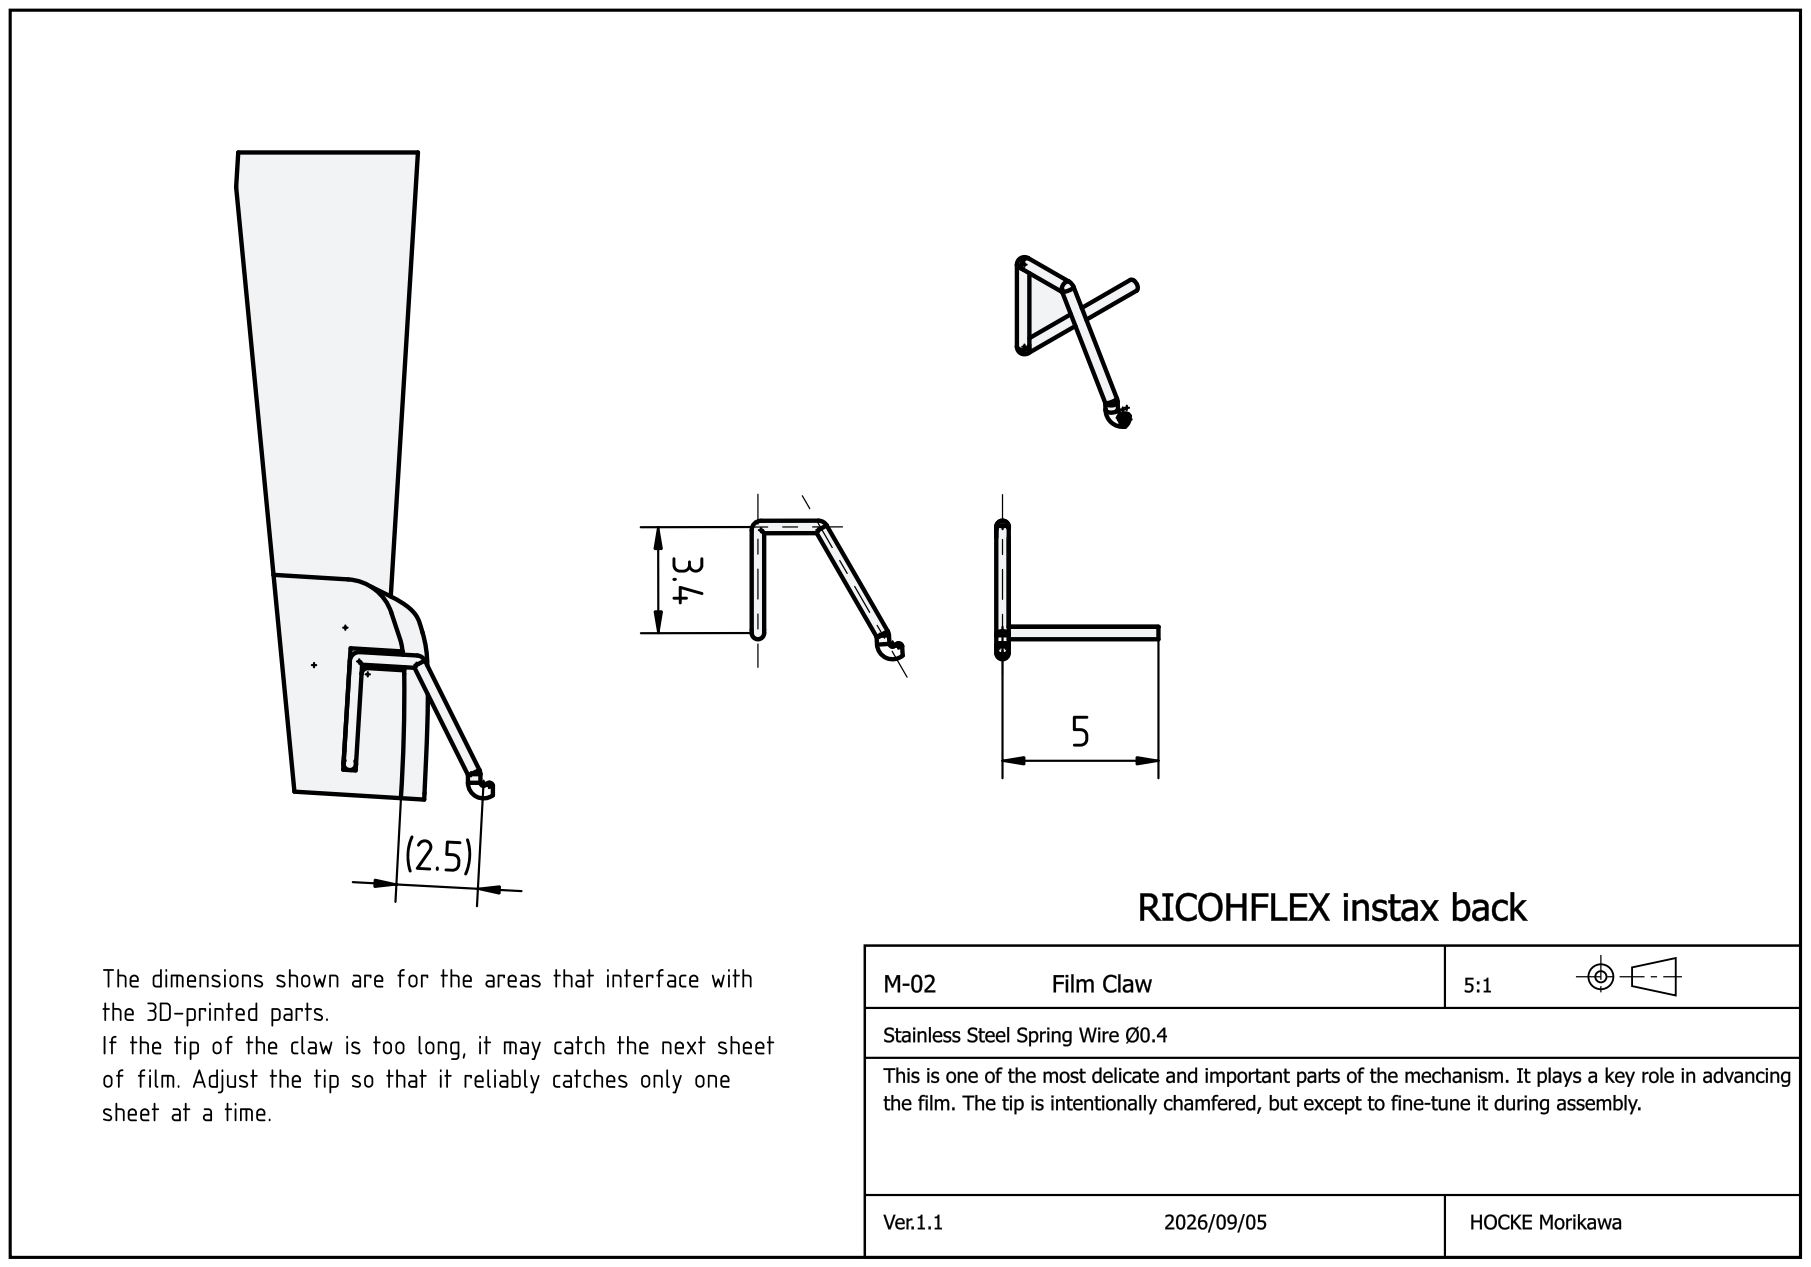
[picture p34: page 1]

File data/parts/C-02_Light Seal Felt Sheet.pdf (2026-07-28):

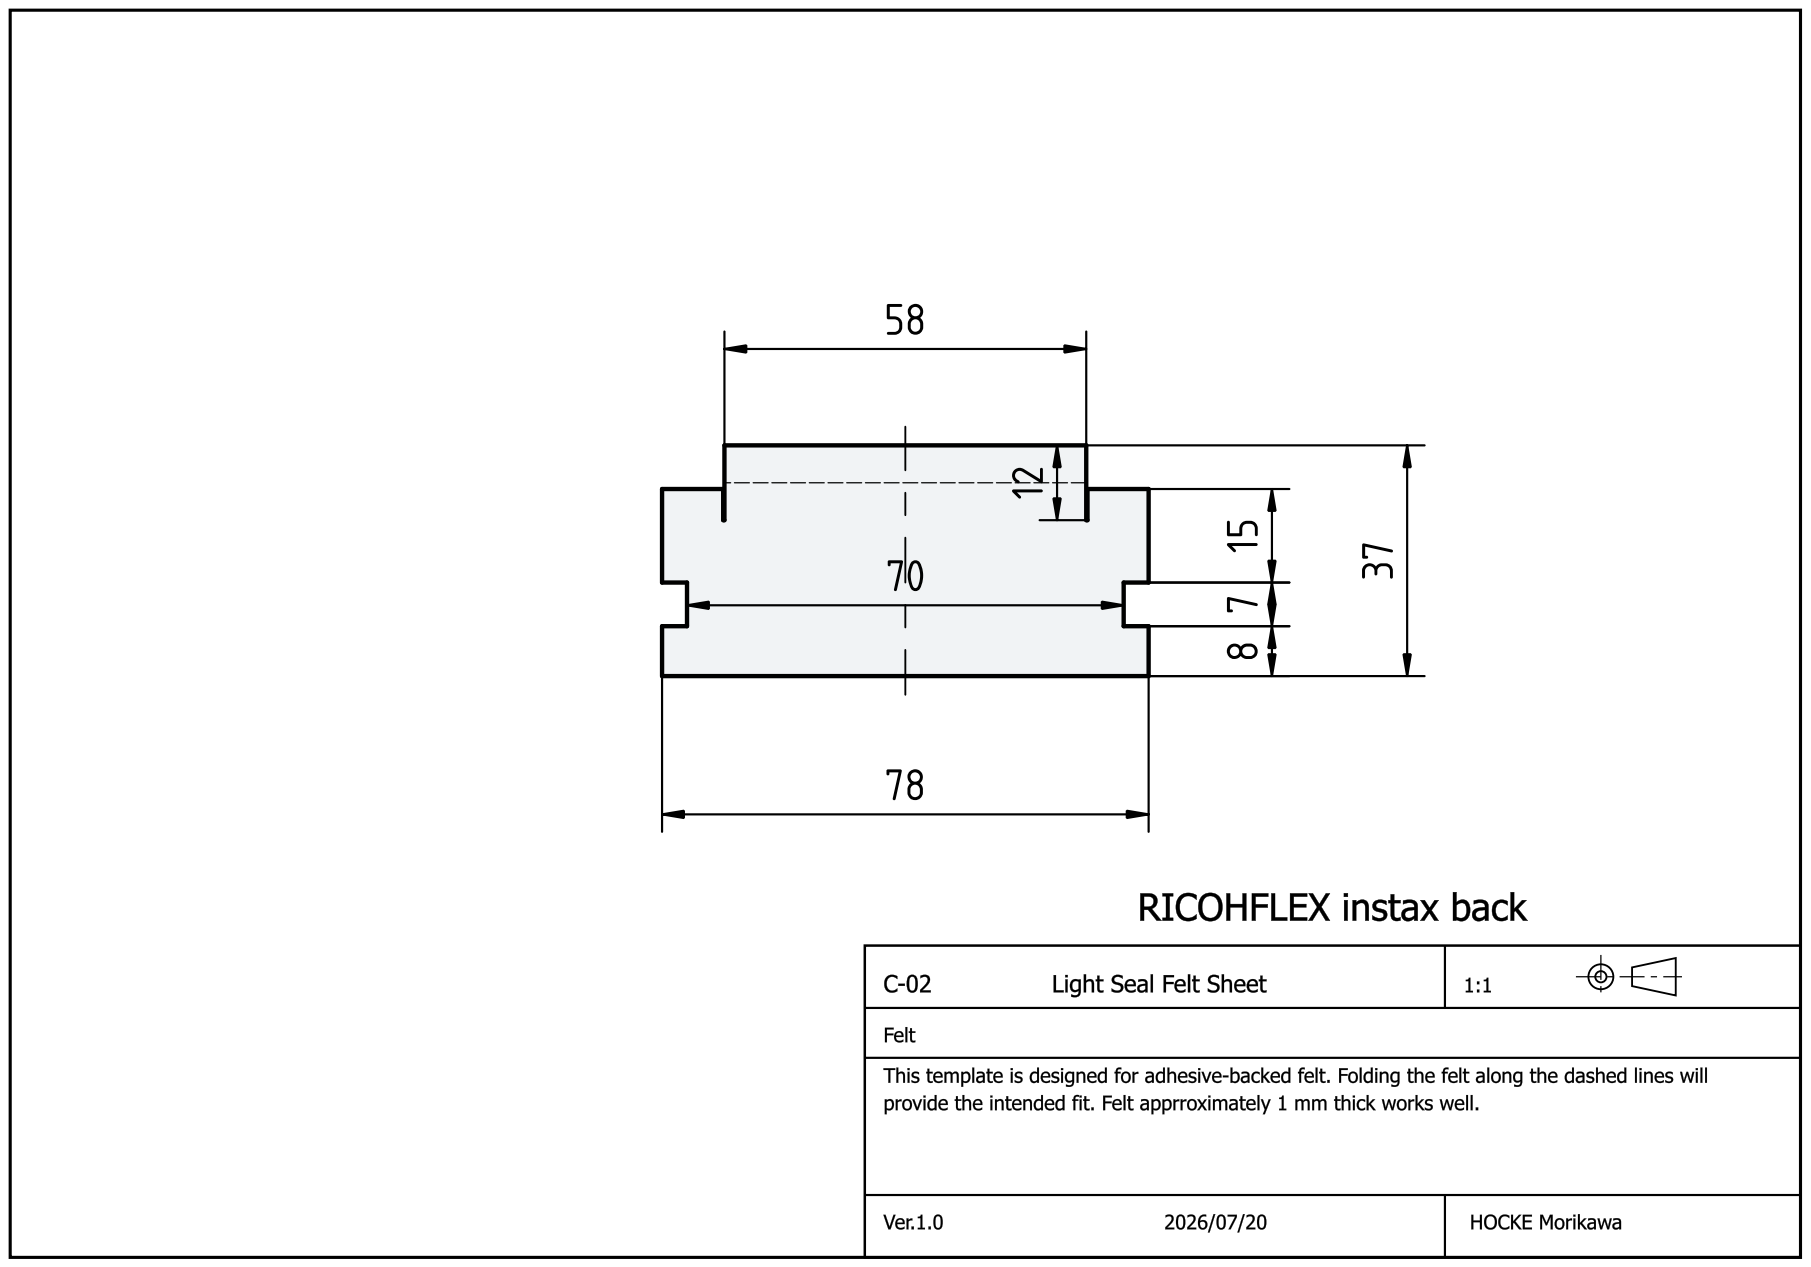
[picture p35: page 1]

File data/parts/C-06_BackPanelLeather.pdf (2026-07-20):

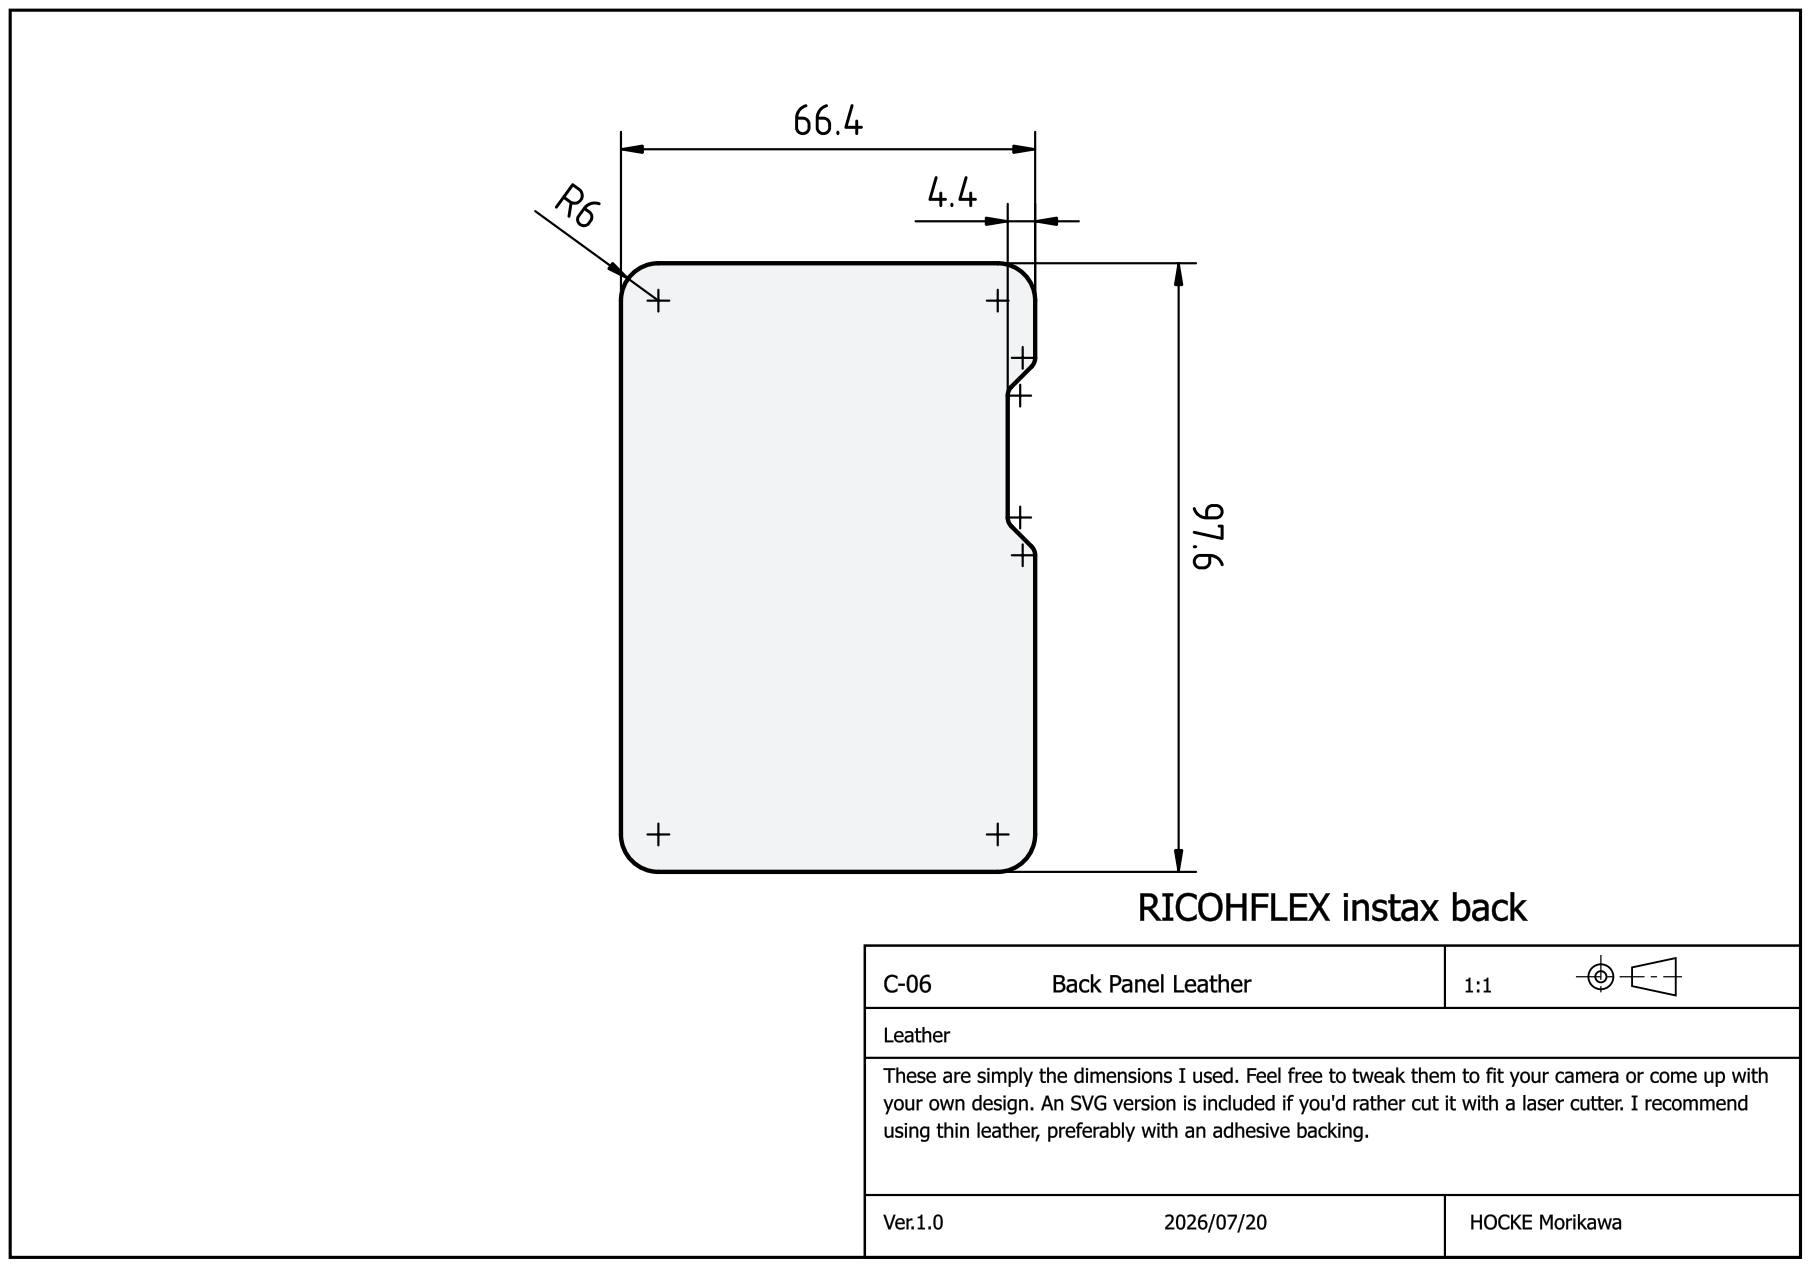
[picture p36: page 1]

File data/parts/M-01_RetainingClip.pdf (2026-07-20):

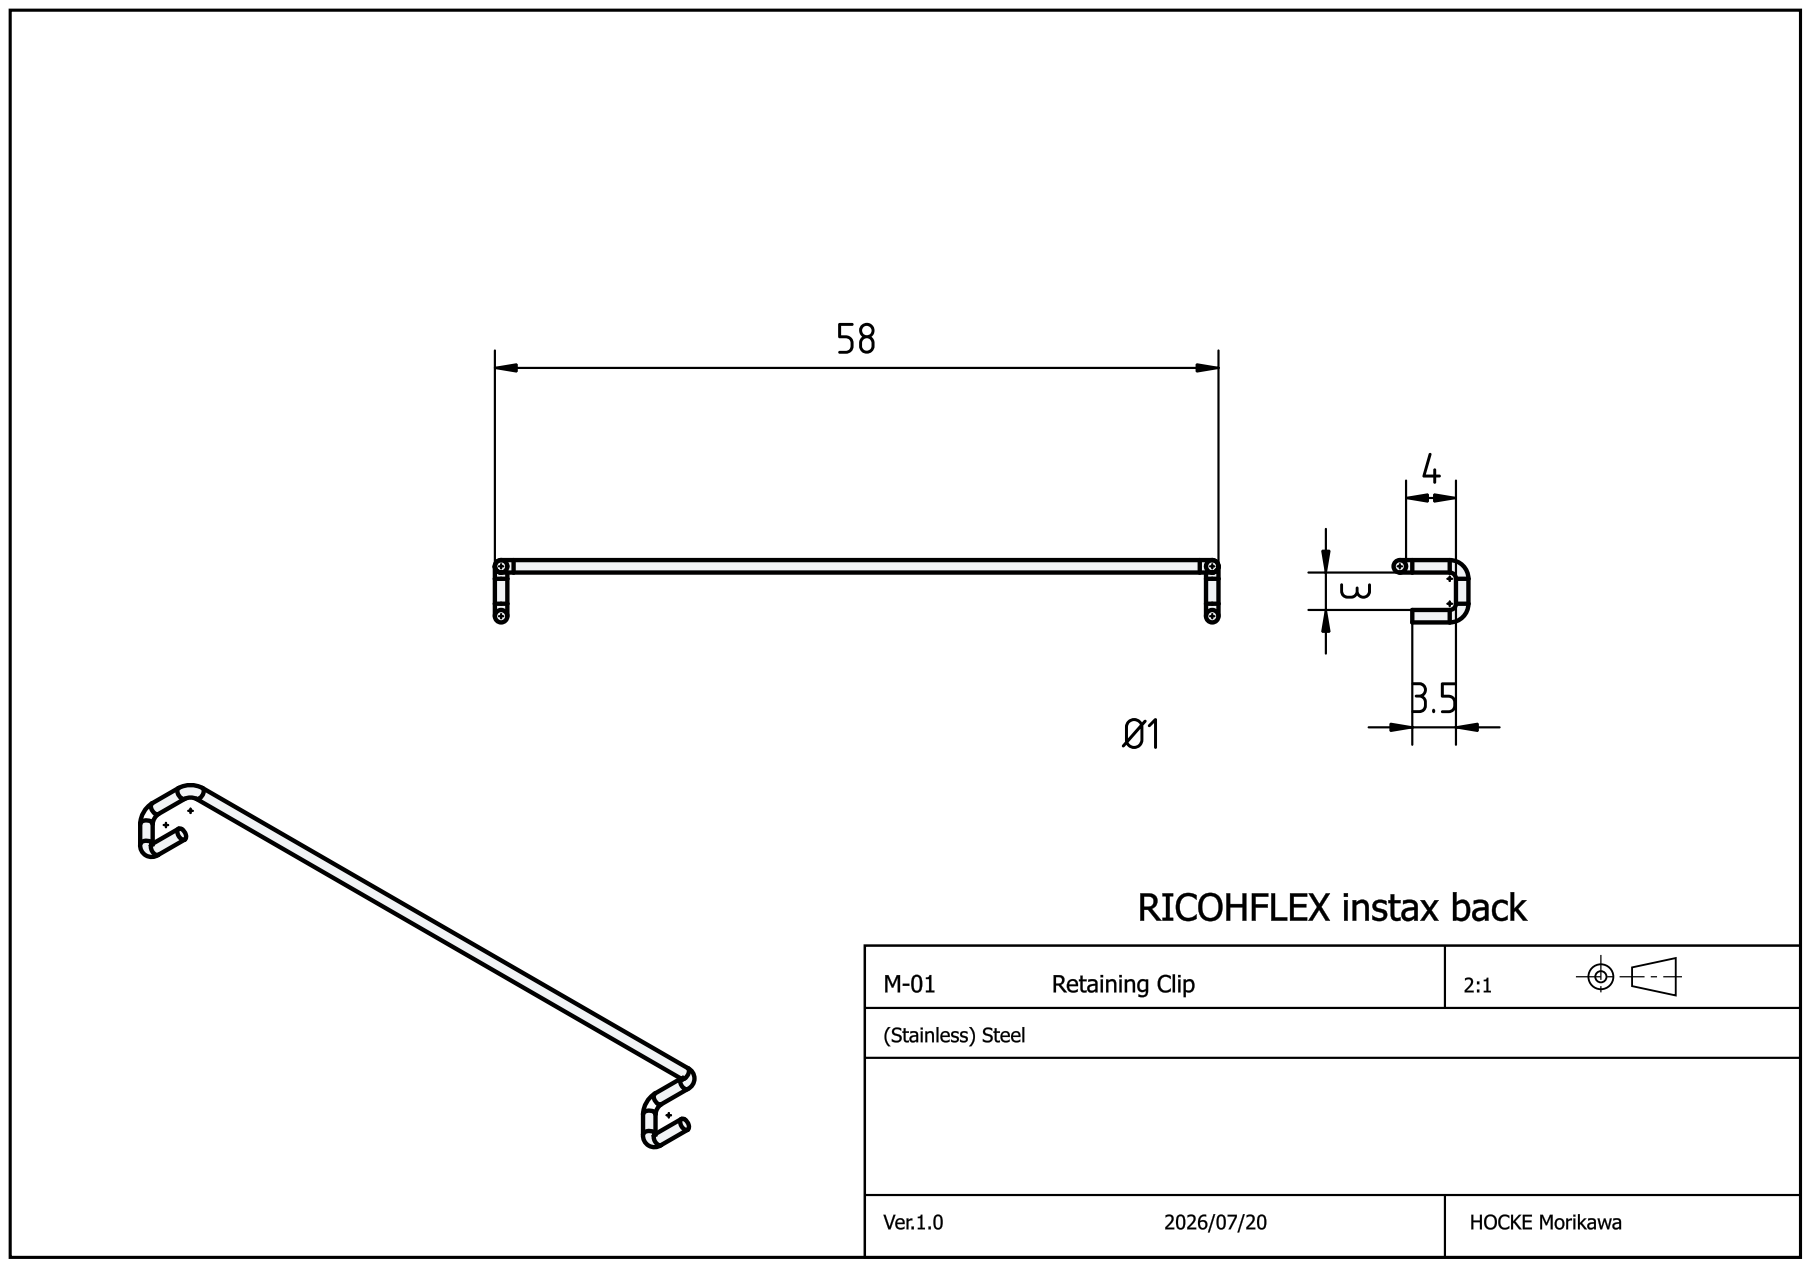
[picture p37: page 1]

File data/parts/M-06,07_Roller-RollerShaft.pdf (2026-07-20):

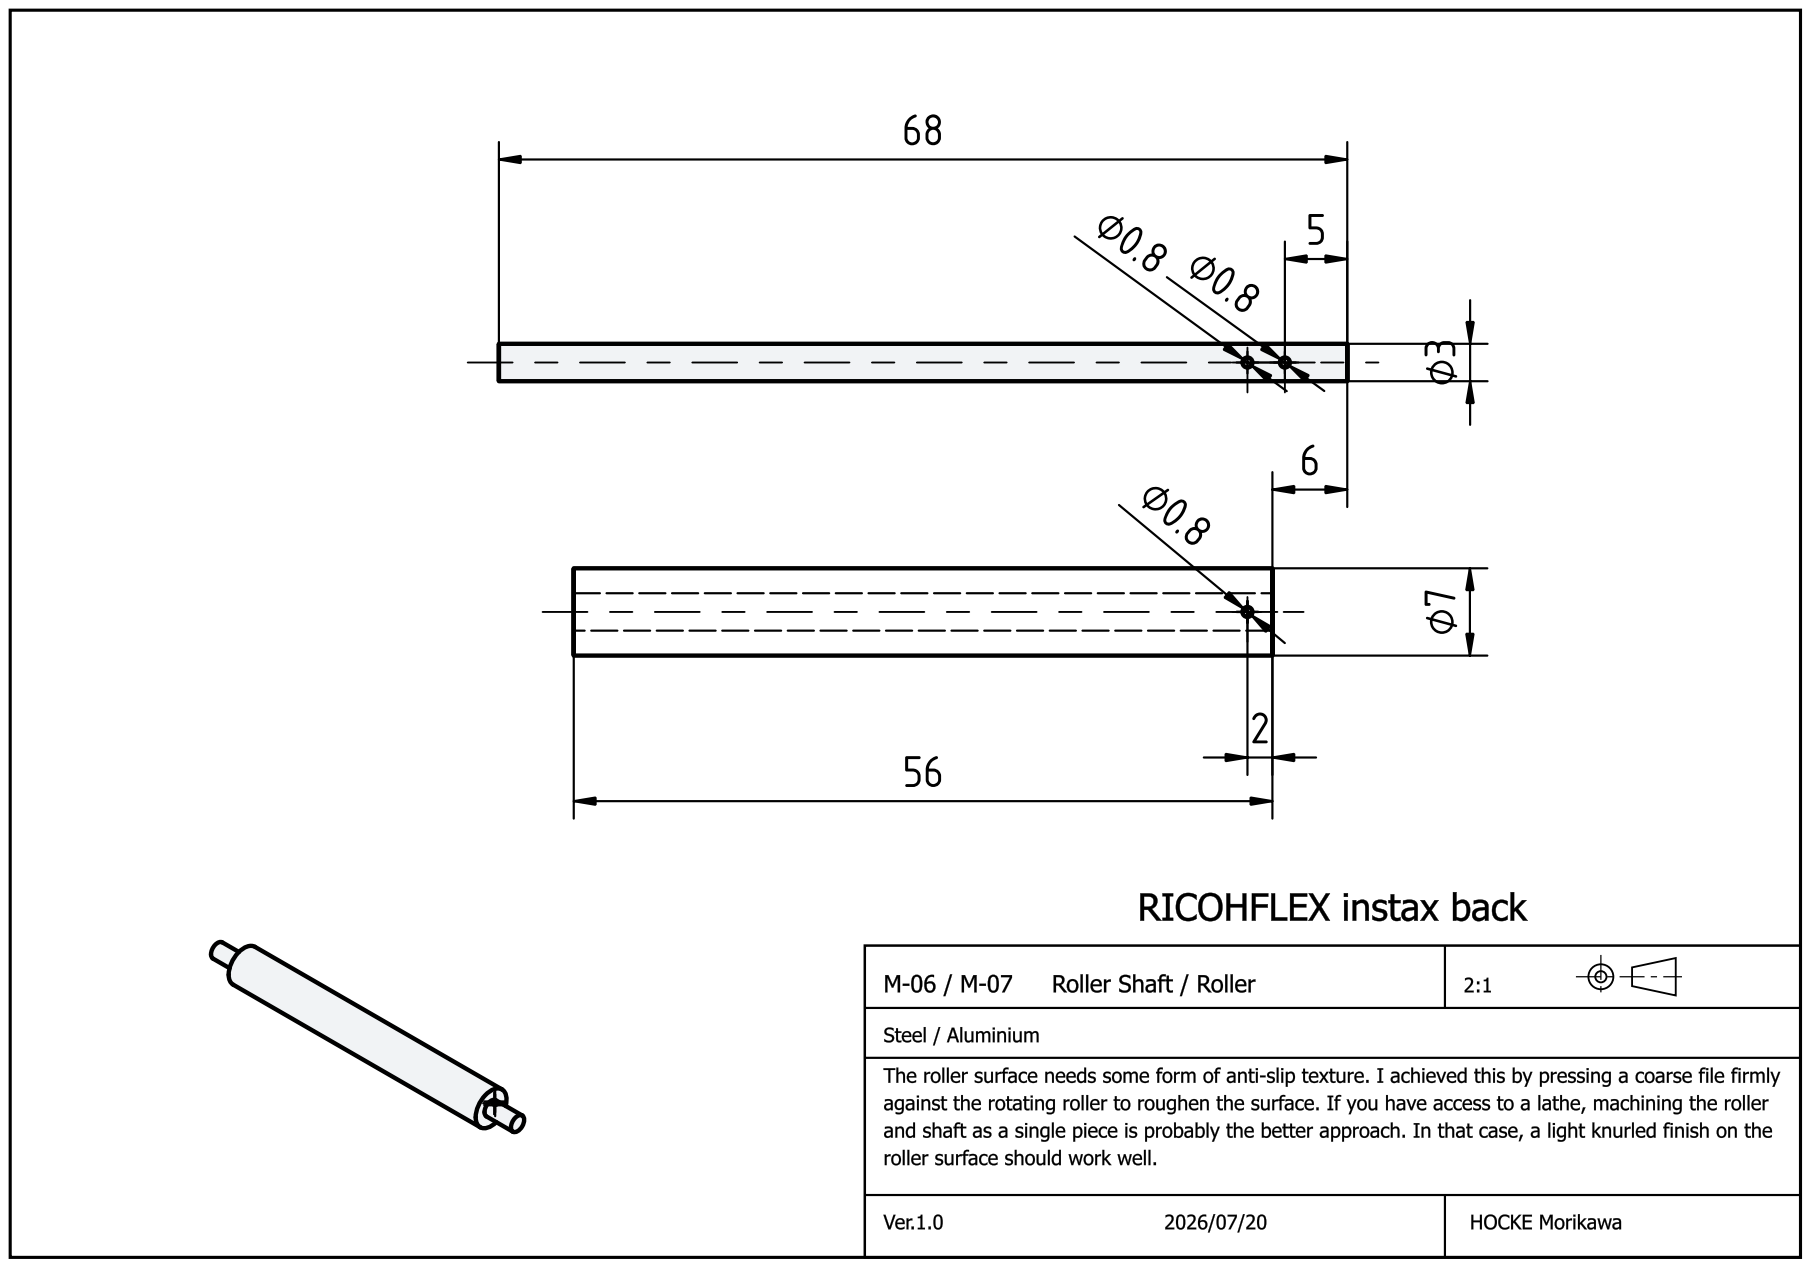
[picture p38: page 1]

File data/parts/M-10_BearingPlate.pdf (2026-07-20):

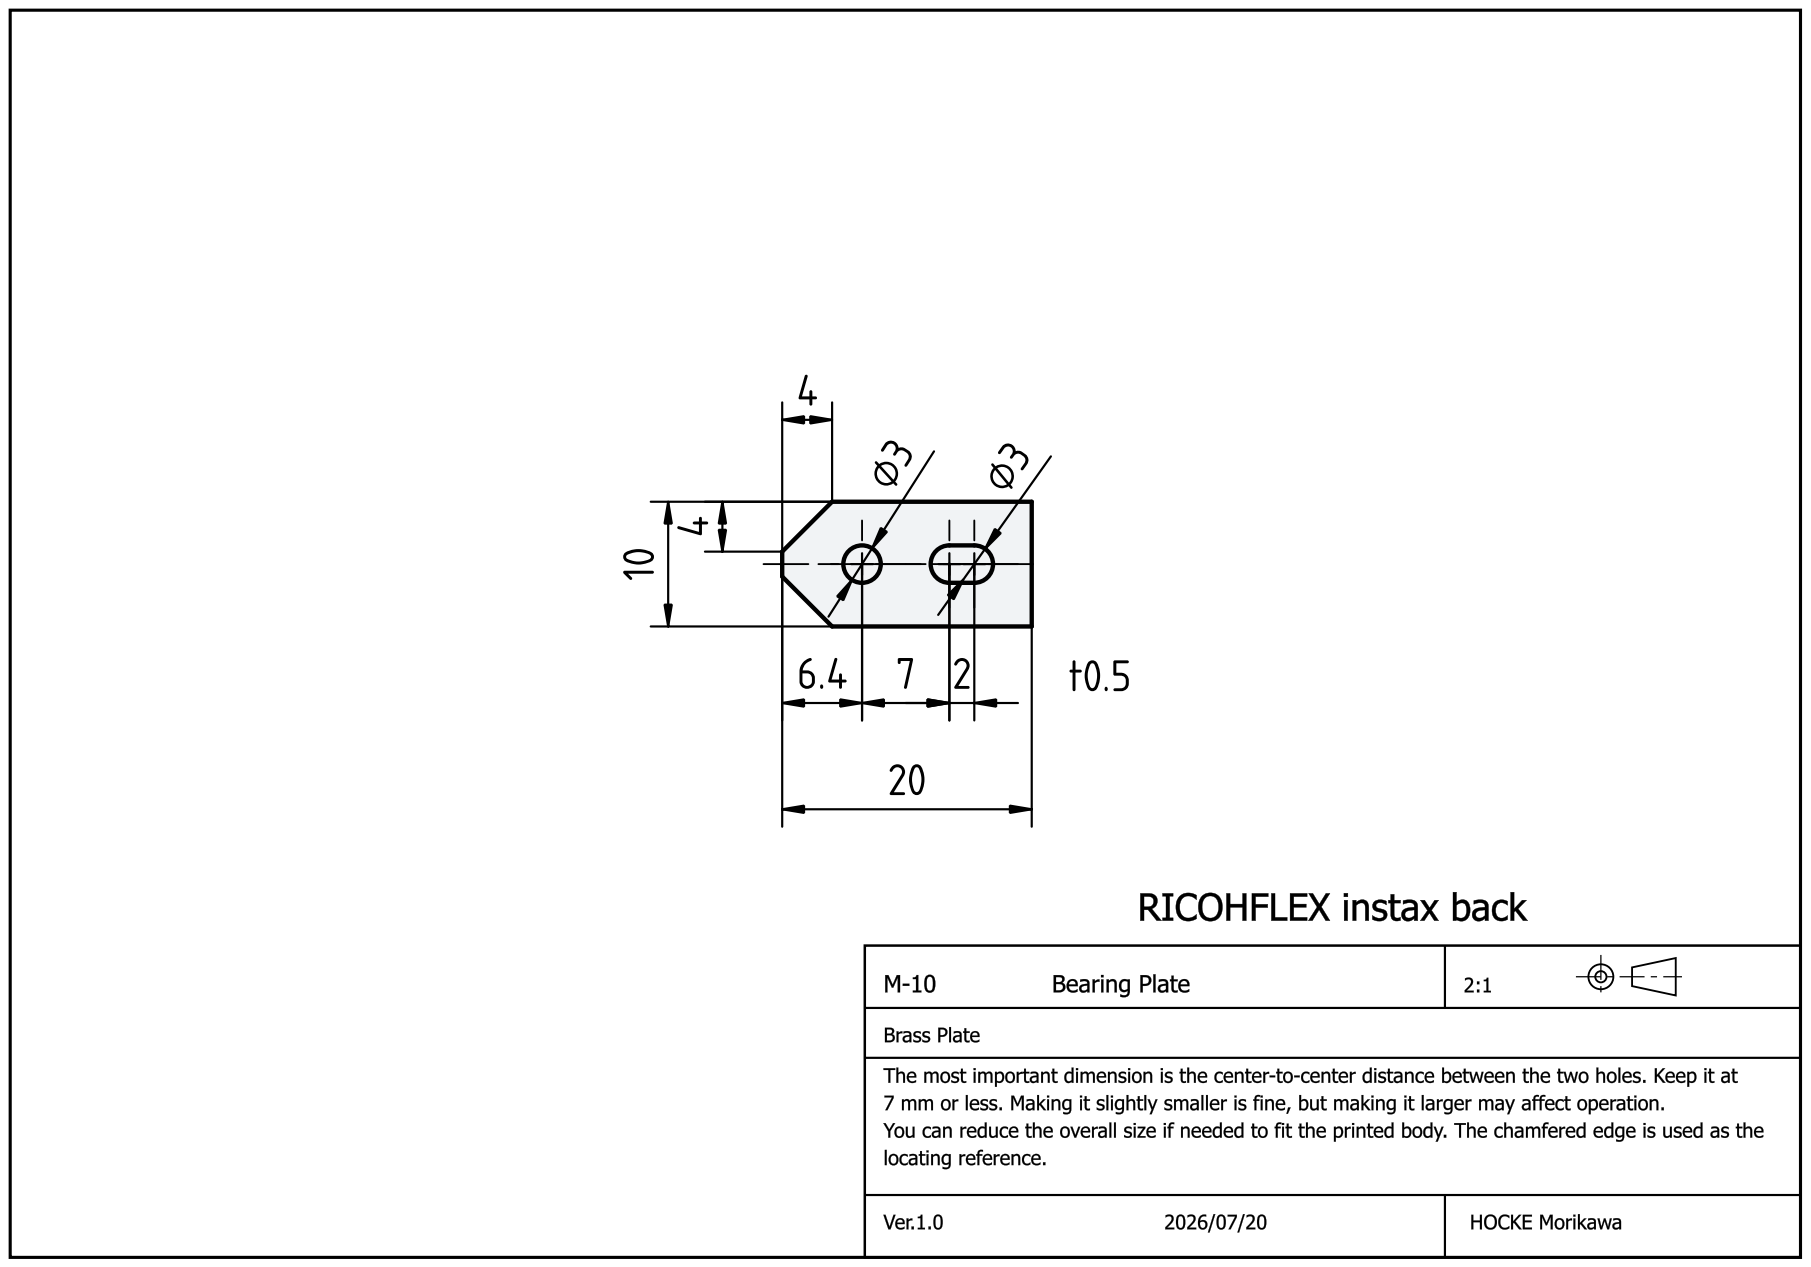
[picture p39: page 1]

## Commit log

2026-07-20 Add data and photos
    [M-01RetainingClip.step, M-02FilmClaw.step, M-11BackPanel.dxf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]
2026-07-20 add extras
    [FilterAdapter37mm.stl, LensHood37mm.stl]
2026-07-20 Reorganize folders
    [FilterAdapter37mm.stl, LensHood37mm.stl, M-01RetainingClip.step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]
2026-07-25 Add data
    [M-01_RetainingClip.step, M-02_FilmClaw.step, M-11_BackPanel.dxf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]
